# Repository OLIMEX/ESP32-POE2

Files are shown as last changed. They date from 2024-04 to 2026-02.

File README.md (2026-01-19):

# ESP32-POE2
Power Over Ethernet Internet of Things POE IoT board with Espressif ESP32 WiFi, Bluetooth and wired 100Mbit Ethehernet with 25W power delivery

https://www.olimex.com/Products/IoT/ESP32/ESP32-POE2/open-source-hardware

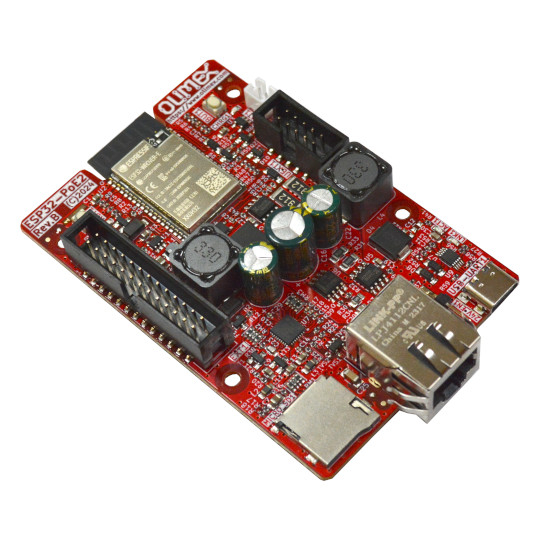
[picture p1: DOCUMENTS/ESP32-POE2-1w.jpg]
ESP32-POE2-1w


## Licensee
* Hardware is released under CERN Open Hardware Licence Version 2 - Strongly Reciprocal
* Box design is released under CC BY 4.0 License
* Software is released under GPL V3 Licensee
* Documentation is released under CC BY-SA 4.0

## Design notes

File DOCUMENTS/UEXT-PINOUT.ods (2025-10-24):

 |  |  |  | UEXT
RESISTOR1 | MUX2 | Signal | Pin# |  | Pin# | Signal | MUX2 | RESISTOR1
- | - | 3.3V OUT | 1 |  | 2 | GND | - | -
NO | NO | GPIO4 | 3 |  | 4 | GPI36 | NO | 10K
2.2K | NO | GPIO333 | 5 |  | 6 | GPIO13 | NO | 10K
10K | SD CMD | GPIO15 | 7 |  | 8 | GPIO2 | SD DATA | 2.2K
NO | SD CLK | GPIO14 | 9 |  | 10 | GPIO5 | NO | 10K
 | 1Some pins have pull-up resistors, that might affect the levels or readings. 2All pins are also routed and available at the EXT1 connector. 3By default ESP32-POE2 is manufactured with ESP32-WROVER module,for ESP32-WROOM module pin #5 would be routed to GPIO16.

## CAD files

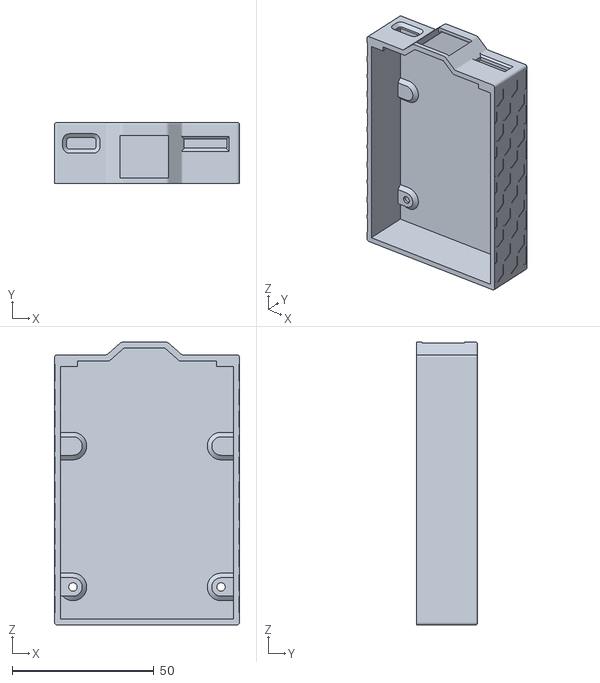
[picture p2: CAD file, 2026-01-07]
HARDWARE/ESP32-PoE2_Rev_B/3D printed case/esp32-poe2 v16_bottom.stl
65.2 x 21.6 x 99.7

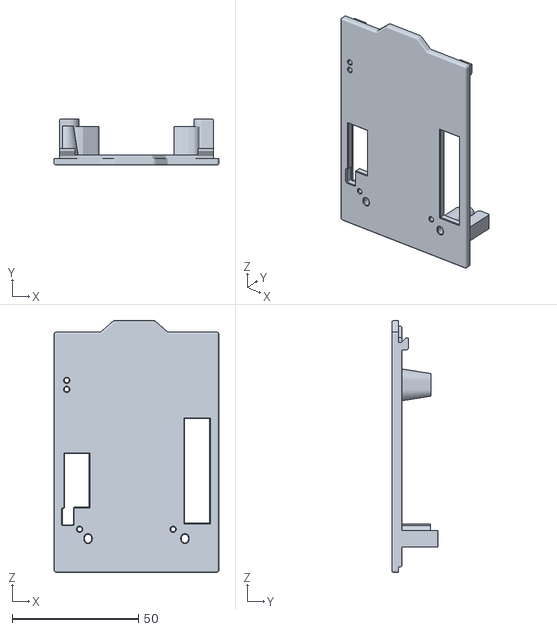
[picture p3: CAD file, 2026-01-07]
HARDWARE/ESP32-PoE2_Rev_B/3D printed case/esp32-poe2 v16_top.stl
65.2 x 18.4 x 99.7

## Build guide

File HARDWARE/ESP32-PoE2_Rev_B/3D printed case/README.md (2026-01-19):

Box can be purchased from here: https://www.olimex.com/Products/IoT/ESP32/BOX-ESP32-POE2/

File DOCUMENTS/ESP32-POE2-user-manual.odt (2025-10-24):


ESP32-POE2

User Manual

Document revision 2.7, October 2025 | www.olimex.com

# 1. Introduction to ESP32-POE2

ESP32-POE2 (https://www.olimex.com/Products/IoT/ESP32/ESP32-POE2/open-source-hardware) is an upgraded version of the popular ESP32-PoE (https://www.olimex.com/Products/IoT/ESP32/ESP32-POE/open-source-hardware) board with more power output capabilities. ESP32-POE2 is an IoT based on ESP32-WROVER-E WIFI/BLE/Ethernet development board with Power-Over-Ethernet feature. The ESP32-POE2 (https://www.olimex.com/Products/IoT/ESP32/ESP32-POE2/open-source-hardware) allows 25W power negotiation and can provide 24V/12V/5V/3.3V to additional equipment connected to it.

The PoE in ESP32-POE2 (https://www.olimex.com/Products/IoT/ESP32/ESP32-POE2/open-source-hardware) is handled by TPS2378 chip that is IEEE 802.3af-compliant, including pre-standard (legacy) PoE support.

The PoE powering requires at least 37V DC to operate successfully. The board can take power from the Ethernet cable and can be expanded with sensors and additional peripherals. Perfect solution for Internet-of-Things projects.

The board is considered Open Source Hardware, design files are released under CERN Open Hardware Licence Version 2 - Strongly Reciprocal. Design files can be found at our GitHub.

Software is released under GPL V3 License and documentation is released under CC BY-SA 4.

+ Important notice: ESP32-POE2 (https://www.olimex.com/Products/IoT/ESP32/ESP32-POE2/open-source-hardware) has no galvanic isolation on Ethernet's power supply, this might be a problem for ground loops. This also means that when you program the board via the micro USB connector the Ethernet cable should be disconnected (if you have power over the Ethernet enabled)! Any board with own external power supply attached to ESP32-POE2 can be dangerous. Consider using Olimex USB-ISO (https://www.olimex.com/Products/USB-Modules/USB-ISO/) to protect your computer and board from accidental short circuit.

## ESP32-POE2 features

- ESP32-WROVER-E-N4R8 – WiFi and bluetooth module with 4MB flash, 8MB PSRAM
- CE-RED and LVD certification
- Original design by OLIMEX Ltd
- Low power design – 200uA consumption in deep sleep
- Ethernet 100Mb interface with IEEE 802.3 PoE support
- USB-C connector for ESP32 programming
- MicroSD card working in 1 bit mode (3 more GPIOs)
- LiPo battery charger with LiPo battery connector
- Battery level monitor pin on ADC
- External power supply detection pin on ADC
- Total output for external circuits – 25W max, max power distributed as follows: - 0.75A at 24V or 1.5A at 12V (selectable by jumper); - 1.5A at 5V; - 1A at 3.3V.
- UEXT (https://www.olimex.com/Products/Modules/) connector
- EXT connector
- User button
- Reset button
- PCB dimensions: (59 x 90)mm ~ (2.32 x 3.54)in

## PoE standard

ESP32-POE2 (https://www.olimex.com/Products/IoT/ESP32/ESP32-POE2/open-source-hardware) follows the original IEEE 802.3af PoE standard and provides up to 25 W of DC power (PoE requires minimum 44 V DC and 350 mA). Only 23 W is assured to be available at the powered device as some power dissipates in the cables.

The board is configured to work in PoE type 2 class 4 mode (PoE+ or IEEE 802.3at) – it draws 12.95 at minimum up to 25.50W maximum. Notice that network equipment usually reserves the maximum wattage for the port, meaning your switch will likely reserve 30W for each ESP32-POE2 connected to it.

The board requires networking equipment that complies with IEEE 802.3at. It is STRONGLY recommended to use isolated PoE equipment.

ESP32-POE2 uses LAN connector that is compatible with both mode A or mode B power delivery method.

## Differences between ESP32-POE2 and ESP32-POE-ISO

ESP32-POE-ISO has limited output voltage range. There are only 5V and 3.3V outputs available, while ESP32-POE2 has also 12V DC or 24V DC.

ESP32-POE2 operates in PoE type 2 class 4 mode (PoE+ or IEEE 802.3at), wherever ESP32-POE-ISO operates in PoE type 1 class 0 mode (PoE or IEEE 802.3af).

ESP32-POE2 (https://www.olimex.com/Products/IoT/ESP32/ESP32-POE2/open-source-hardware) is NOT galvanically isolated which means that it’s not safe to connect it to other devices which use non-isolated power supply. ESP32-POE-ISO is galvanically isolated.

+ YOU SHOULD NOT CONNECT ESP32-POE2 to computer’s USB port while it’s powered by Ethernet POE!!! If you connect USB while ESP32-POE2 is powered by Ethernet you will damage the board or your computer or both. This also voids the warranty!

+ The board is susceptible to grounds loops. Make sure your PoE network equipment is isolated. Measure for voltage difference between different grounds before attaching devices to ESP32-POE2.

+ The most optimal setup for the board is being connected just to the PoE Ethernet cable and all attached peripherals are attached only to ESP32-POE2. No sources of power with different grounds should be attached at the same time. Additional boards that are attached to ESP32-POE2 and are also attached to other sources of power supply (being powered from other sources) can also cause problems!

## Order codes for ESP32-POE2 and accessories

ESP32-POE2 (https://www.olimex.com/Products/IoT/ESP32/ESP32-POE2/open-source-hardware) Commercial temperature grade 0-70C board with internal antenna

USB-CABLE-A-TO-C-1M (https://www.olimex.com/Products/Components/Cables/USB-CABLE-A-TO-C-1M/) 1 meter USB-A to USB-C cable for ESP32-POE2 powering and

programming

Ethernet-CABLE-1M (https://www.olimex.com/Products/Components/Cables/Ethernet-CABLE-1M/) 1 meter Cat 5e Gigabit Ethernet cable with unshielded RJ45 connectors

BOX-ESP32-POE2 (https://www.olimex.com/Products/IoT/ESP32/BOX-ESP32-POE2/) Plastic box for ESP32-POE2

USB-ISO (https://www.olimex.com/Products/USB-Modules/Isolators/USB-ISO/) Galvanic USB isolator to protect your PC from electrical problems with ESP32-POE2

BATTERY-LIPO1400mAh (https://www.olimex.com/Products/Power/Lipo-battery/BATTERY-LIPO1400mAh/) Lipo battery 3.7V 1400mAh – note these batteries can be shipped only by ground so we can deliver only to EU destinations.

UEXT modules (https://www.olimex.com/Products/Modules/) Different sensors, relays, LCDs, RTC, GSM, GPS, accessories which can be connected to UEXT connector

# 2. Hardware

## ESP32-POE2 layout

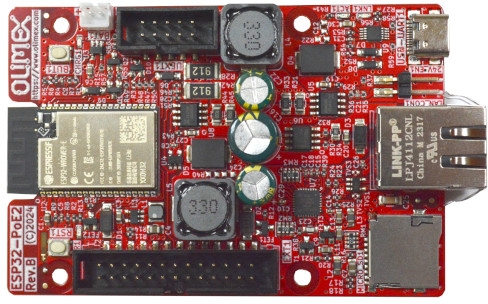
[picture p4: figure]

MicroSD card

(1-bit SD mode)

12V/24V jumper selector

LiPo battery connector

User button BUT1

EXT1 connector

RESET button RST1

Ethernet connector

USB-C for power and programming

UEXT connector

## ESP32-POE2 pins and connectors

+ ESP32 chip and modules have very good pin multiplexing. You can define any free GPIO pin for almost any goal.

+ ESP32-POE2 uses WROVER chip, and it uses GPIO16 and GPIO17 for PSRAM. This is important when you are defining the pins for the Ethernet or using GPIO16 at the UEXT.

ESP32-POE2 with WROVER module remaps GPIO16 to GPIO33 (so, for example, at UEXT pin #5 you have GPIO33 instead of GPIO16) and GPIO17 to GPIO0 (this is the Ethernet clock source).

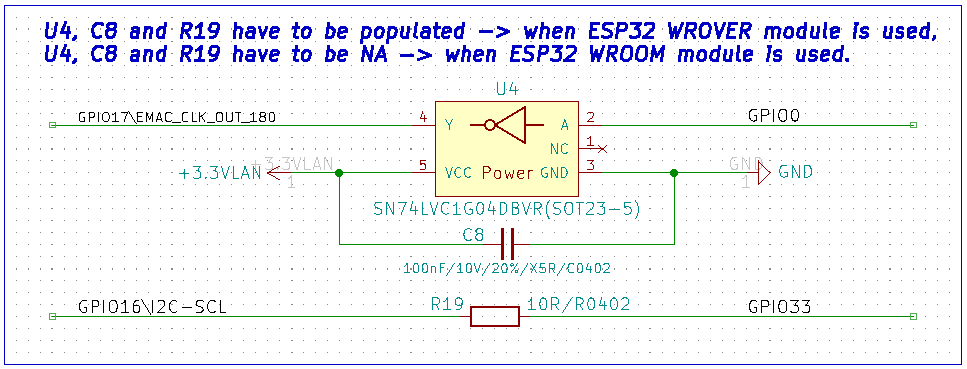
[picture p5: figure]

### Power sense and battery level measurement

- External power sense available on GPI39

- Battery measurement disabled by default (for an additional free GPIO), but can be enabled by SMT jumper change

- Close SMT jumper BAT_SENS_E1 (solder its pads together) to enable battery measurement on GPI35.

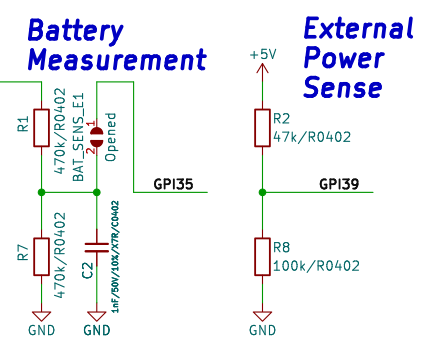
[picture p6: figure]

Notice about the battery measurement resistor divider coefficient is 2 = (R1+R7)/R7 and maximum battery charger voltage is around 4.2V, this leaves ADC values up to 2.1V. This means VREF needs to be set in ADC_ATTEN_DB_11 range (150 mV ~ 3100 mV).

### Buttons

The ESP32-POE2 board has two button. One user button BUT1 and a reset button RST1.

By default button BUT1 is a user button since the board automatically enters bootloader mode. It is connected to GPI34 (GPIO34 can only be input, hence we’ve named it GPI34). Notice that BUT1 can be configured as on-demand BOOT button if you solder R6 pads together (or if you solder 0R resistor in 0402 package on same R6 pads). BOOT button can then be used to manually force boot mode.

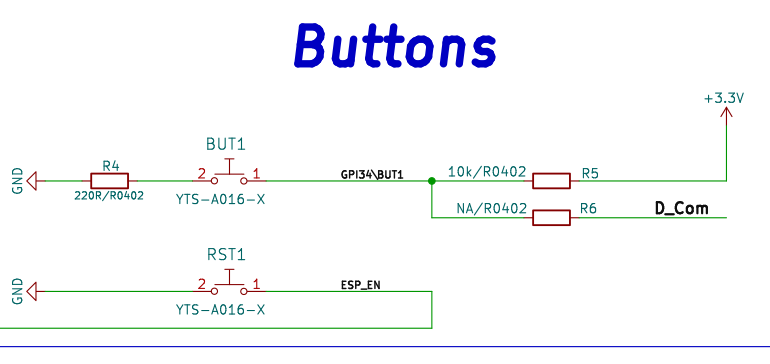
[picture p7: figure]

### SD card connector (1-bit SD interface)

Notice that the SD card pins are multiplexed with pins #7, #8, #9 of the UEXT (typically used for SPI). If you wish to use those pins at the UEXT you’d have to time share with the SD card using the different chip selects. It is important to notice the SD card is configured in 1-bit SD mode when considering the software.

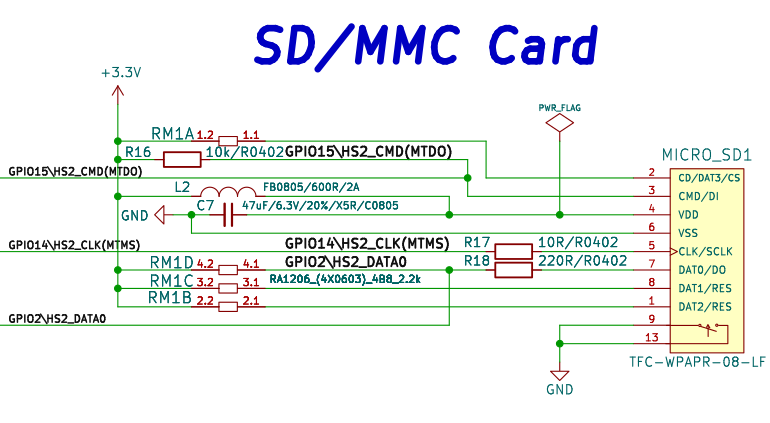
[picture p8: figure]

### UEXT connector

UEXT connector stands for Universal EXTension connector and contain +3.3V, GND, I2C, SPI, UART signals. It is usually used to attach external modules without soldering.

UEXT is 0.1” 2.54mm step boxed plastic connector. All signals are at 3.3V levels. GPIO16 is replaced by GPIO33 in boards with ESP32 WROVER module (all ESP32-POE2 boards use WROVER, so this is always true).

Pins #7, #8, #9 are multiplexed with the SD card, if you don’t have or you don’t need SD card it is fine to use, else you’d need to time-share the functionality between the UEXT and the SD card (using the different chip selects).

These are suggested usage for the pins for compatibility with Olimex-made modules, but since ESP32 chip has good multiplexing they can be defined for other uses. Notice that you need to define the pins in your code (e.g. define them via software means) for the intended usage. For example, if you use GPIO33 for I2C SCL and GPIO13 for I2C SDA you need to define them in your code (in Arduino IDE it is usually done with “Wire.begin (13, 33);”).

Olimex has developed number of MODULES (https://www.olimex.com/Products/Modules/) with this connector. There are temperature, humidity, pressure, magnetic field, light sensors. Modules with LCDs, LED matrix, Relays, Bluetooth, Zigbee, WiFi, GSM, GPS, RFID, RTC, EKG, sensors and etc.

You can find excerpt from the schematic of the UEXT on the next page.

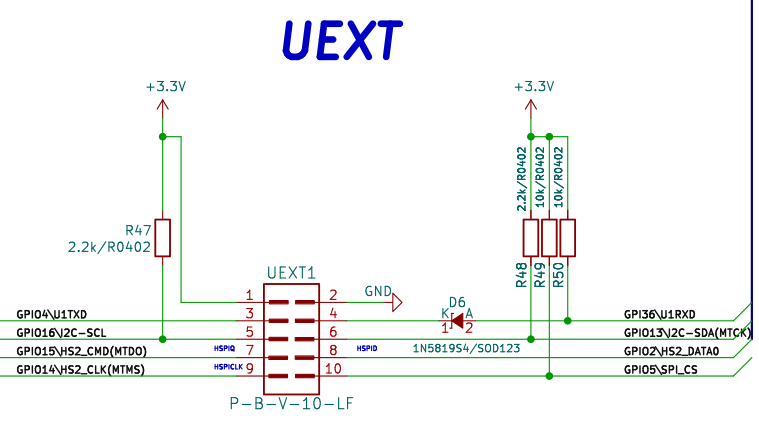
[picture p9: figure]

Important: GPIO16 is replaced by GPIO33 due to the board using WROVER chip (the schematic is made for both variants, but WROVER variant was never manufactured).

### EXT1 connector

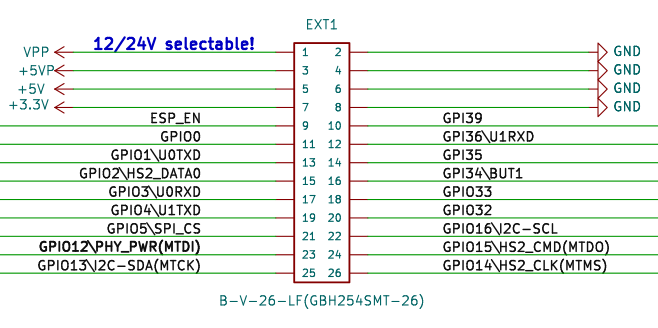
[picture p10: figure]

Again notice about GPIO33 and GPIO16, when the WROVER module is used (by default), there is no GPIO16! And GPIO33 goes to both pin #18 and pin #22!

Same for GPIO0 – it will be used for Ethernet clock, if you decide it for other uses it will affect the Ethernet!

### Power supply

VPP selectable 12V/1.5A or 24V/0.75A output from PoE, depending on 24V_E1 PTH jumper state

+5VP 5V/1.5A output from PoE

+5V 1. can be output or input;

2. when board is connected to USB or to Ethernet PoE this line can be used as output and power other circuits;

3. if you want to use as input i.e. to power the board from external 5V on this pin sure board is not connected to the USB!

+3.3V output which can source up to 0.5A @ 3.3V i.e. (1.65W)

### GPIOs

ESP_EN resets ESP32 module;

GPIO0 is used for Ethernet clock;

GPIO16, GPIO17 are used for the PSRAM;

GPIO1 is used for the serial line and programming;

GPIO2, GPIO14, GPIO15 are used for the SD-card, if no SD card is present these are free to use, else you can time-share using the chip select;

GPIO2, GPIO4, GPIO5, GPIO13, GPIO14, GPIO15, GPIO33, GPIO36 are shared on both UEXT and EXT1,2 headers so if you use them at one connector do not use at the other;

GPIO33 is routed in place of GPIO16 at the header and the UEXT (since the board uses WROVER chip);

GPI39 is used to measure external power supply voltage;

GPI34 is connected to used button and have 10K pullup;

GPI35 is free to use but can be connected to measure the LiPo battery voltage if SENS_BAT_E1 solder jumper.

Notice that pins named GPI* can only be inputs (unlike GPIO*). This is limitation from the ESP32 chip itself.

## ESP32-POE2 schematics

ESP32-POE2 (https://www.olimex.com/Products/IoT/ESP32/ESP32-POE2/open-source-hardware) latest schematic is on GitHub (https://github.com/OLIMEX/ESP32-POE2)

## ESP32-POE2 powering details

(https://www.olimex.com/Products/Retro-Computers/AgonLight2/open-source-hardware)

ESP32-POE2 (https://www.olimex.com/Products/IoT/ESP32/ESP32-POE2/open-source-hardware) can be powered by 4 sources:

- Ethernet PoE, notice this is class 4 PoE device requires at least 12.95W and can go up to 25.5W. Notice that your network equipment will allocate the maximum wattage for the port, usually around 30W per device; this is important if you connect multiple ESP32-POE2 boards to the same piece of PSE (Power Sourcing Equipment)!
- USB-C connector
- LiPo battery
- EXT1 pin 5 (+5V) note that this signal is connected to USB 5V signal so when you power with this pin you should not connect the board to the USB! If possible avoid powering from EXT1 to avoid accidental short-circuit!

Power consumption of ESP32-POE2 (https://www.olimex.com/Products/IoT/ESP32/ESP32-POE2/open-source-hardware) is between 50mA and 200mA depending on the operation mode.

A LiPo battery gets charged automatically from other sources of power with about 100mA.

When the LiPo battery is attached and external power supply is missing internal DCDC step-up converter and switching circuit automatically powers ESP32-POE2 from the battery. 1400mAh battery will provide about 8 hours of stand alone operation.

+The LiPo battery connector is JST 2.0 mm connector and with Olimex’s battery polarity. If you use batteries from other manufacturers please make PLUS and MINUS are connected properly else you will damage the board!!!

# 3. Dimensions

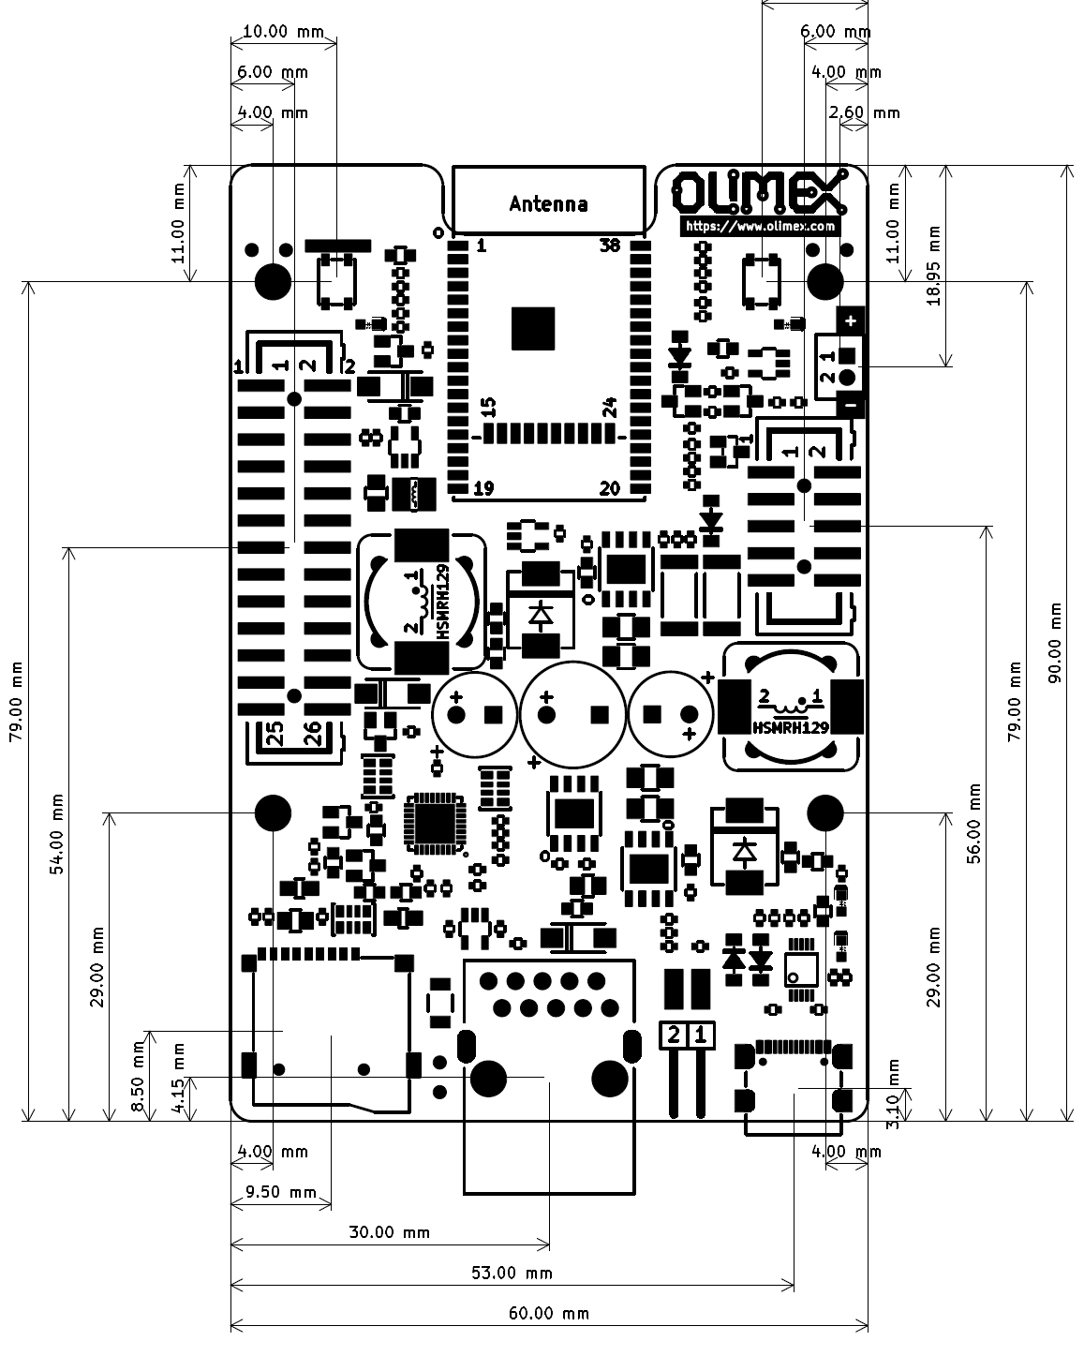
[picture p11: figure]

# 4. Software

(https://www.olimex.com/Products/IoT/ESP32/ESP32-POE2/open-source-hardware)

ESP32-POE2 (https://www.olimex.com/Products/IoT/ESP32/ESP32-POE2/open-source-hardware) uses same software as ESP32-POE which is very popular board and supported by

- Espressif ESP-IDF (https://docs.espressif.com/projects/esp-idf/en/latest/esp32/get-started/)
- MicroPython (https://micropython.org/download/OLIMEX_ESP32_POE/)
- Arduino IDE (https://github.com/OLIMEX/ESP32-POE/tree/master/SOFTWARE/ARDUINO)
- Esphome (https://github.com/esphome/bluetooth-proxies/blob/main/olimex-esp32-poe-iso.yaml)
- PlatformIO (https://docs.platformio.org/en/latest/boards/espressif32/esp32-poe.html)

In your software (for example, Arduino IDE) make sure to enable the PSRAM in the board selector (when board is with ESP32-WROVER-E)!

Software notices:

- Ethernet notice – For the Ethernet operation make sure to properly set the GPIO for the Ethernet clock and the pin for the power enable pin! GPIO12 is used as PHY power pin and GPIO0 is used as clock output pin (when board uses ESP32-WROVER-E module). Under Arduino defines should be like (must be defined before ETH.h):

#ifndef ETH_PHY_TYPE

#define ETH_PHY_TYPE ETH_PHY_LAN8720

#define ETH_PHY_ADDR 0

#define ETH_PHY_MDC 23

#define ETH_PHY_MDIO 18

#define ETH_PHY_POWER 12

#define ETH_CLK_MODE ETH_CLOCK_GPIO0_OUT

#endif

#include <ETH.h>

- I2C (TWI) notice – since the board uses WROVER chip to define the I2C pins at the UEXT connector use GPIO13 for SDA and GPIO33 for SCL. For example, to define in Arduino IDE use:

Wire.begin(13, 33);

Remember to include <Wire.h> at the beginning:

#include <Wire.h>

# 5. FAQ (Frequently Asked Questions)

- Help! Ethernet is not working always upon power-up. If I press the reset or power cycle the board a few times sometimes it starts working. Is my device faulty?
  It is probably because your software didn’t utilize the PHY_PWR pin (GPIO12) properly. This behavior happens when the PHY controller (LAN8720) gets powered before the ESP32 module can generate the PHY clock. What your software should do is hold the LAN8720 in reset for few milliseconds via the PHY_PWR pin and release it from reset only after PHY clock is already generated by the ESP32 module. Simple software workarounds that can be tested are adding delay before Ethernet initialization or toggling GPIO12 to reset only the Ethernet chip until connection is restored.
- Ethernet doesn't work. Is my board defective?
  Make sure you've selected board variant with PSRAM enabled (this board has WROVER module, not WROOM). Make sure your code defines GPIO0 as Ethernet clock source pin.
- Where are the I2C, UART, SPI pins exposed?
  The ESP32 chip has very advanced multiplexing and you can define any free GPIO pin for I2C, UART, SPI operation as long as you are within the maximum supported (some penalties to SPI's maximum frequency apply, when not using the dedicated pins). Notice that some ESP32 pins can only be inputs. Double check if the pins you want to use are free. Defining pins for another function is a purely software effort.
- I want to use the I2C pins at the UEXT but I have problems. I have defined pins 13 and 16 for the I2C. What is the problem?
  The I2C pins at the UEXT are 13 and 33. Pin 16 gets replaced by pin 33 due to the board using WROVER chip (instead of WROOM). Refer to page 9.
- I provide 24V to the Ethernet of ESP32-POE2's but it doesn't seem powered. What is the problem?
  TPS2375PW (Si3402) would NOT work with 24V DC. The recommended voltage is 48V DC and the minimum is around 37V DC. For more info refer to TPS2375PW's (Si3402-B's) datasheet.
- I power the board from the battery connector. The LEDs remain off. Is it broken?
  Probably not. This is a low-power design. The LEDs would not turn on when operating on battery to save power. You need other ways to determine if it works or not. For example, something over the serial lines or over the Ethernet (with no PoE enabled else it would get powered from there).
- What is the power delivery mode of these boards? Is it mode A or mode B?
  ESP32-POE2 uses LAN connector that is compatible with both mode A or mode B. Either one is fine.
- What is the PoE class of ESP32-POE2?
  ESP32-POE2 is set for type 2 class class 4 PoE operation (12.95W-25.5W). Class 4 operation might require more current since it requires at least 12.95W up to 25.5W. Notice that your network equipment will allocate the maximum wattage for the port, usually around 30W per device; this is important if you connect multiple ESP32-POE2 boards to the same piece of PSE (Power Sourcing Equipment)! If you have trouble with powering multiple devices from the same switch then refer to the schematic and unsolder the resistor R34 to switch back to class 0 operation. (0.44W to 12.95W), but this will reduce the wattage available from the board, roughly half of the wattage only will be available.
- R28 and R42 get very hot! What are these components? Are they safe? Can I remove them?
  These resistors are required by the IEEE standards. They are used to maintain power signature (MPS). Search online "maintain power signature poe" to get the general idea.
  Lack of load causes availability problems when using ESP32 power saving modes – the board would consume less wattage than PoE equipment can detect, which leads to PoE equipment shutting the ESP32 board off.
  If you are not using the low power modes of the ESP32 board and the heat from the resistor bothers you, you might try desoldering R28 and R42 and see if that effects your setup negatively. If the board gets shut down, solder them back. Notice that we don't recommend doing so.

# 6. Document revision history

Revision 2.7 October 2025

-Expanded FAQ section;

-Reworked UEXT connector table;

-Expanded I2C clarifications (GPIO16→GPIO33 due to WROVER chip);

-General minor improvements.

Revision 2.6 September 2025

-Clarified multiplexing and cleared UEXT section

Revision 2.5 September 2025

-Added FAQ section

Revision 2.4 March 2025

-Minor improvements and fixes

Revision 2.3 August 2024

-Additional notes about software setup for Ethernet and board selection

Revision 2.2 May 2024

-Fixed mistakes in GPIO descriptions

Revision 2.2 May 2024

-Fixed mistakes in GPIO descriptions

Revision 2.1 May 2024

- Added dimensions;

- Spelling improvements.

Revision 2.0 May 2024

- Fixed wrong info about ESP32 module – the board is manufactured with WROVER module, not WROOM;

- Clarified warnings about isolation;

- Added some extra info about different GPIOs;

- Spelling improvements.

Revision 1.0 April 2024

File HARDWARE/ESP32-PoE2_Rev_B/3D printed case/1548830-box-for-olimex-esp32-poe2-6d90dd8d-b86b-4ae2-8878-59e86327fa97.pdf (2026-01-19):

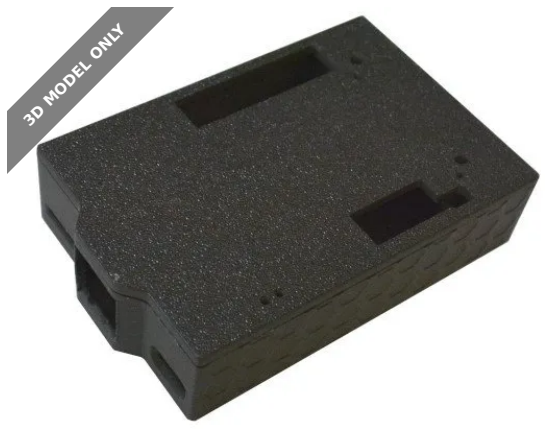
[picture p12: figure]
3D MODEL ONLY

## Summary

ESP32-PoE2 is an Open Source Hardware ESP32-powered WIFI/BLE/ Ethernet development board with Power-Over-Ethernet feature

Gadgets (https://printables.com/model?categoryId=21) > Computers (https://printables.com/model?categoryId=27)

Tags: | esp32 | olimex | esp32poe2

Github project page: OLIMEX/ESP32-POE2: Power Over Ethernet Internet of Things POE IoT board with Espressif ESP32 WiFi, Bluetooth and wired 100Mbit Ethehernet with 25W power delivery (https://github.com/OLIMEX/ESP32-POE2)

Product page: ESP32-POE2 - Open Source Hardware Board (https://www.olimex.com/Products/IoT/ESP32/ESP32-POE2/open-source-hardware)

ESP32-PoE2 is an Open Source Hardware ESP32-powered WIFI/BLE/ Ethernet development board with Power-Over-Ethernet feature.
The PoE is handled by TPS2378PW chip that is IEEE 802.3-compliant, including pre-standard (legacy) PoE support. The PoE powering requires at least 37V DC to operate successfully. The board takes power from the Ethernet cable and can be expanded with sensors and more. Perfect solution for Internet-of-Things projects.
ESP32-POE2 operates in the commercial temperature range (0-70) degrees C.
ESP32-POE2 can power external circuits with 24V/0.75A or 12V/1.5A plus experify3d (https://printables.com/@experify3d_271079)

## Box for Olimex ESP32-POE2

VIEW IN BROWSER (https://printables.com/model/1548830-box-for-olimex-esp32-poe2)

updated 9. 1. 2026 | published 9. 1. 2026

## Model files

5V/1.5A plus 3.3V/1A up to total of 25W of power output. This is when the board is powered from the Power-Over-Ethernet connector.

## License

This work is licensed under a GNU

General Public License v3.0 (https://www.gnu.org/licenses/gpl-3.0.html)

✖ | Sharing without ATTRIBUTION
✔ | Remix Culture allowed
✔ | Commercial Use
✔ | Meets Open Definition
ℹ | Share under the same license

esp32-poe2-v16_top.stl

esp32-poe2-v16_bottom.stl

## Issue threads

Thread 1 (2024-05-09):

Ethernet SD card demo  - esp_eth_driver_install_failed (PlatformIO)

DO7LZ, 2024-05-09:
Hi,

I tried to get the [Simple Ethernet and SD card demo for Arduino](https://raw.githubusercontent.com/OLIMEX/ESP32-POE/master/SOFTWARE/ARDUINO/ESP32_PoE_Ethernet_SD_Card_Arduino/ESP32_PoE_Ethernet_SD_Card_Arduino.ino) example working with PlatformIO. But there seems to be an error with the Ethernet libary.

```
rst:0x1 (POWERON_RESET),boot:0x1b (SPI_FAST_FLASH_BOOT)
configsip: 0, SPIWP:0xee
clk_drv:0x00,q_drv:0x00,d_drv:0x00,cs0_drv:0x00,hd_drv:0x00,wp_drv:0x00
mode:DIO, clock div:2
load:0x3fff0030,len:1184
load:0x40078000,len:13232
load:0x40080400,len:3028
entry 0x400805e4
Card Mounted
E (664) lan87xx: lan87xx_pwrctl(409): power up timeout
E (665) lan87xx: lan87xx_init(491): power control failed
E (665) esp_eth: esp_eth_driver_install(215): init phy failed
[   674][E][ETH.cpp:324] begin(): esp_eth_driver_install failed
```

What I did:

1. Create a new PlatformIO project with board **OLIMEX ESP32-PoE** and Framework Arduino. (platformio/espressif32 v6.6.0)
2. Pasted in the above mentioned example into `main.cpp` and added `monitor_speed = 115200` to `platformio.ini`
3. Inserted SD card and plugged in network and USB to board.
4. Build and upload. Followed by the console output above.

Can anyone give me a little push?

JulesThuillier, 2024-05-16:
Hi !

Same issue here.
Also I cannot get I2C device to work using your basic sample (https://github.com/OLIMEX/ESP32-POE/blob/master/SOFTWARE/ARDUINO/ESP32_PoE_MOD_BME280/ESP32_PoE_MOD_BME280.ino)
Please adivse.

JulesThuillier, 2024-06-06:
@DO7LZ have you found a solution ?

DanKoloff, 2024-06-07:
Regular ESP32-POE config is not suitable for ESP32-POE2. If there is ESP32-POE-WROVER or ESP32-POE-ISO-WROVER config it would be suitable.

ESP32-POE2 uses ESP32-WROVER module that uses GPIO16 and GPIO17 for the internal PSRAM, so you need to define GPIO0 for the Ethernet clock (instead of GPIO17). Else the Ethernet won't work.

And if you need to use GPIO16 (usually used for I2C) change it with GPIO33.

jonathanelmgren, 2024-06-24:
In the latest firmwares of Micropython you should use `ref_clk` and `ref_clk_mode` to set the clock mode for `network.LAN`.

I got it working with this code:

```
import network
import machine
import time

def initialize_ethernet():
    # Configure the PHY power pin as a machine.Pin object
    phy_power = machine.Pin(12, machine.Pin.OUT)
    phy_power.value(0)  # Start with PHY power off
    time.sleep(1)
    phy_power.value(1)  # Power up the PHY
    time.sleep(1)  # Wait for the PHY to power up

    # Define the MDC and MDIO pins as machine.Pin objects
    mdc_pin = machine.Pin(23)
    mdio_pin = machine.Pin(18)
    ref_clk_pin = machine.Pin(0)

    try:
        # Initialize the LAN interface with the correct PHY type and parameters
        lan = network.LAN(
            mdc=mdc_pin,  # MDC pin as machine.Pin
            mdio=mdio_pin,  # MDIO pin as machine.Pin
            power=phy_power,  # PHY power pin as machine.Pin
            phy_type=network.PHY_LAN8710,  # PHY type
            phy_addr=0,  # PHY address
            ref_clk=ref_clk_pin,  # Reference clock pin as machine.Pin
            ref_clk_mode=machine.Pin.OUT,  # Reference clock mode as output
        )
        lan.config(hostname="esp32-ethernet-client")
        lan.active(True)
        time.sleep(2)  # Allow the interface to stabilize

        while True:
            if lan.isconnected():
                print("Ethernet is supported and connected.")
                print("Network config:", lan.ifconfig())
            else:
                print(
                    "Ethernet is supported but not connected. Please connect an Ethernet cable."
                )
            time.sleep(5)
    except Exception as e:
        print("Error initializing Ethernet:", e)

# Run the initialization function
initialize_ethernet()
```

Working both with PoE and USB with regular Ethernet. Firmware used was https://micropython.org/download/ESP32_GENERIC/ and latest release from `Firmware (Support for SPIRAM / WROVER)` section

DO7LZ, 2024-10-11:
My solution for the problem:

Create a new PlatformIO project with board Espressif **ESP-WROVER-KIT** instead of OLIMEX ESP32-PoE and Framework Arduino.

Paste the example in `main.cpp` and add the following directly before `#include <ETH.h>`:

```
#ifndef ETH_PHY_TYPE
#define ETH_PHY_TYPE ETH_PHY_LAN8720
#define ETH_PHY_ADDR 0
#define ETH_PHY_MDC 23
#define ETH_PHY_MDIO 18
#define ETH_PHY_POWER 12
#define ETH_CLK_MODE ETH_CLOCK_GPIO0_OUT
#endif
```

This is also mentioned in the actual user manual.
With this the example seems to work. It's getting an IP address via DHCP and is able to send a GET request to google.com and prints out the response. On push of BUT1 the files are properly written to SD card. I don't have tested any other things yet.

Closed 2024-10-11.

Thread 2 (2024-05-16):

I2C does not does work on pins 13 - 16. Why is GPIO16 connected to GPIO33 through a 10ohm resistor

JulesThuillier, 2024-05-16:
Using the ESP-POE2 board and Olimex BME280 board I tried the simple example provided by Olimex (https://github.com/OLIMEX/ESP32-POE/blob/master/SOFTWARE/ARDUINO/ESP32_PoE_MOD_BME280/ESP32_PoE_MOD_BME280.ino), the I2C communication with BME280 does not work. Using a protocol analyser I see data on SDA (GPIO13) but SCL (GPIO16) is always HIGH.

Moving forward with my investigation, I look at ESP-POE2 schematic and see the following connection :
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
Can somebody explain why is this here ?

So I tried to replace SCL pin with GPIO5, and tada ! It works.
It is not really a solution in itself because your UEXT connectors uses GPIO16 for SCL.

Last test was to remove R19, and still did not work. I finally stumbled on this piece of information :
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

And that seems to be the answer. It's a bit confusing that this exact pin was chosen for UEXT SCL pin...
Any plan to fix this ?

DanKoloff, 2024-06-07:
This is not an issue to fix. Just we designed the board to be suitable for two types of ESP32 modules - with or without PSRAM (our ESP32-POE and ESP32-POE-ISO modules are designed the same modules).

The ESP32 module without PSRAM is ESP32-WROOM and the ESP32 module with PSRAM is called ESP32-WROVER.

By default in ESP32-POE2 we place the ESP32-WROVER module with PSRAM.

The difference between ESP2-WROOM and ESP32-WROVER is that the ESP32-WROVER uses two of the GPIOs for the PSRAM (GPIO16 and GPIO17). So in boards with ESP32-WROVER module (like ESP32-POE2) - Ethernet clock is GPIO0 instead of GPIO17 and GPIO33 is routed to the UEXT (instead of GPIO16).

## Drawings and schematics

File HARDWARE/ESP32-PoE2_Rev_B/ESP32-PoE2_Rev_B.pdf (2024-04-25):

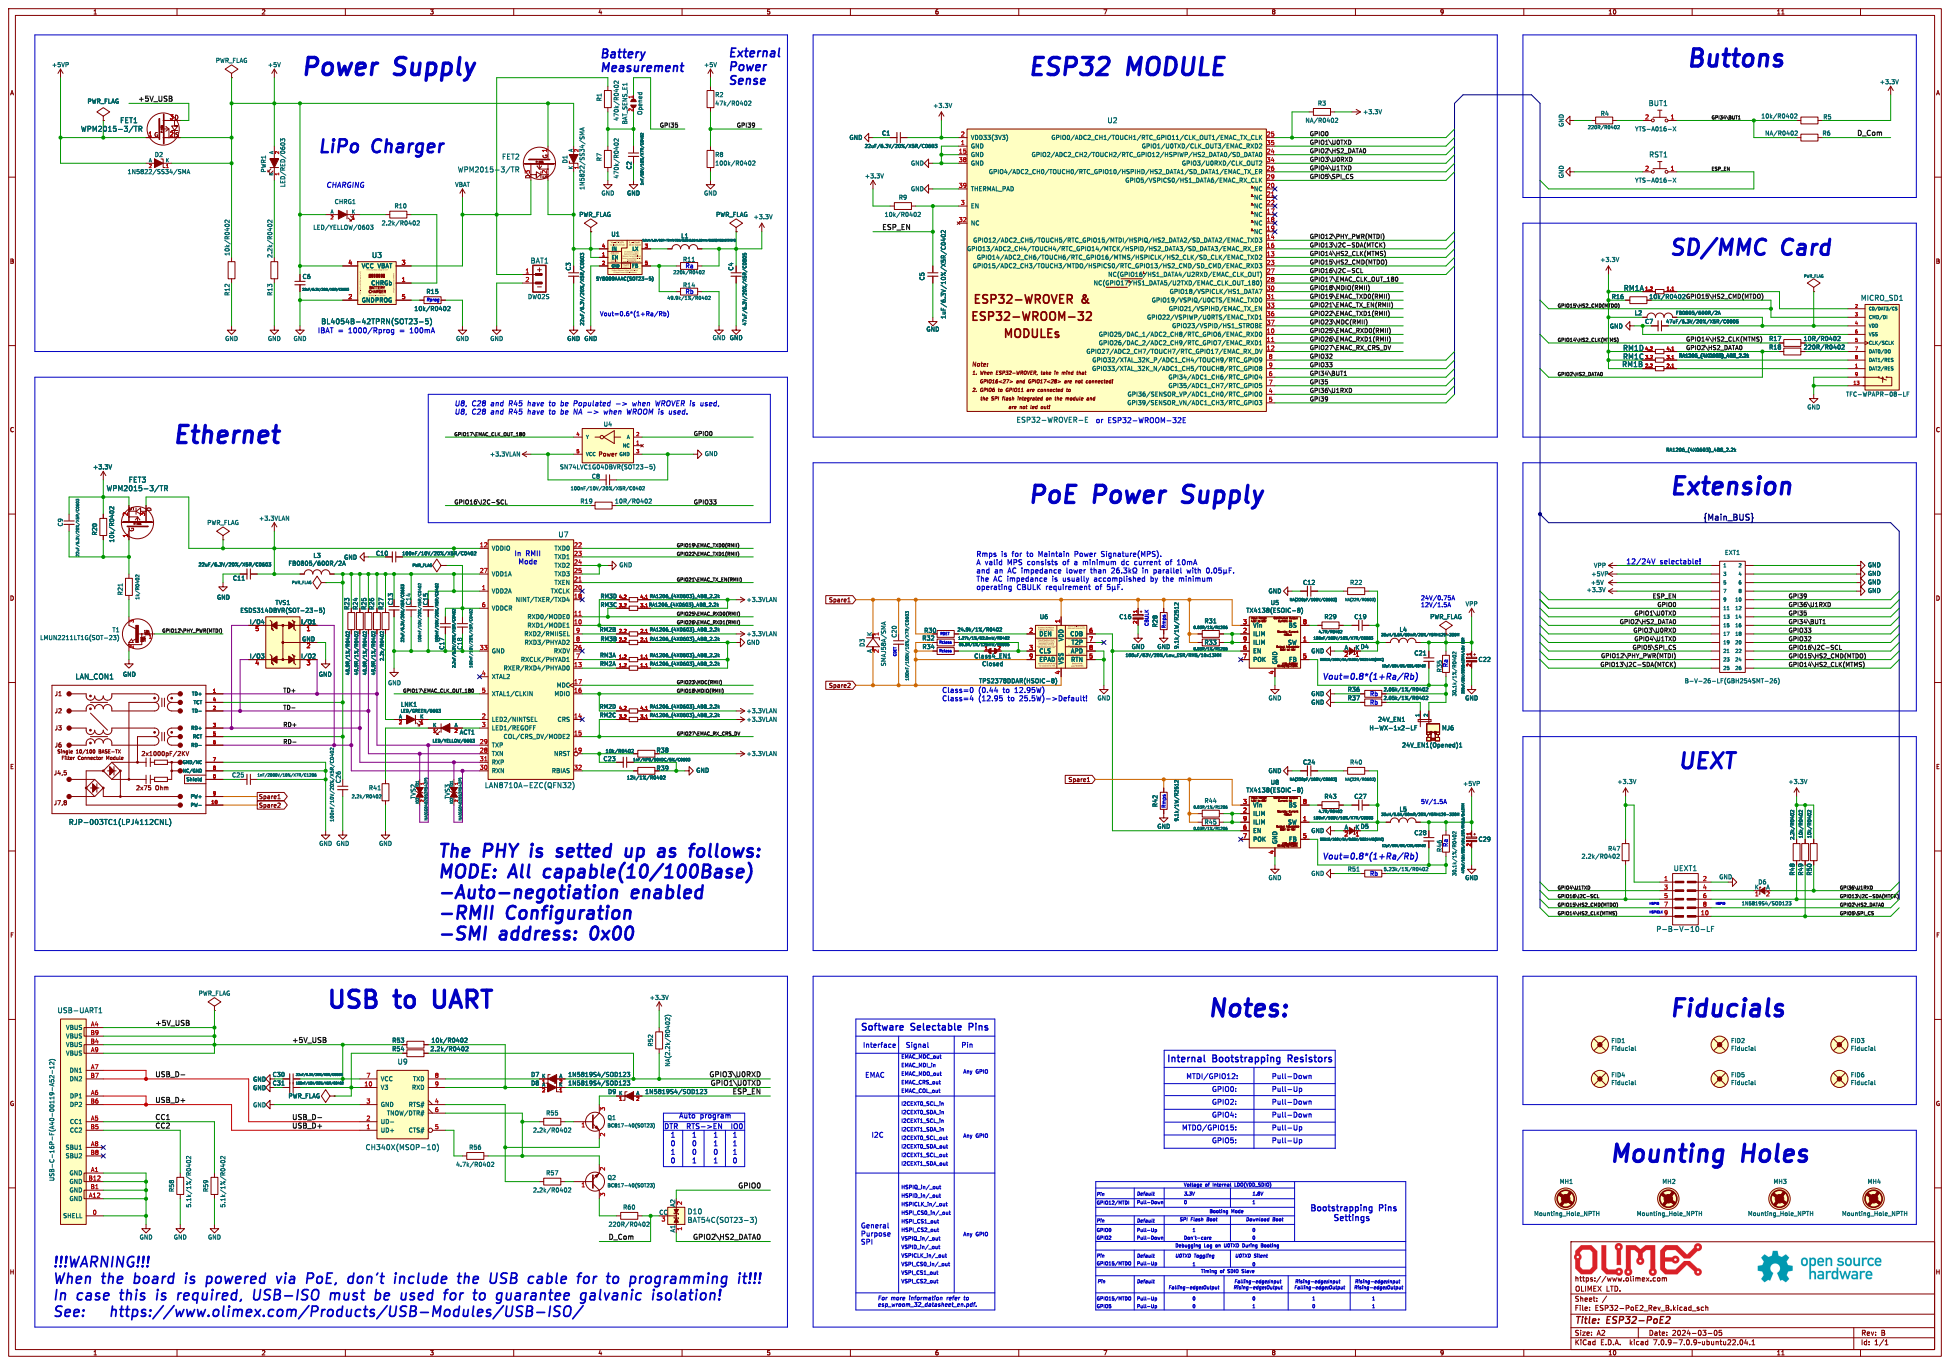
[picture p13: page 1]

2. 2. 2. 2. 2. 2. 2. GPIO6 to GPIO11 are connected to
22 GPIO15/ADC2_CH3/TOUCH3/MTDO/HSPICS0/RTC_GPIO13/HS2_CMD/SD_CMD/EMAC_RXD3

Donotfloat. Enablecontrol. FB Input Current,I(FB)=50nA(max) FeedbackReferenceVoltage,V(REF)=0.6V

are not led out! ESP32-WROOM-32

4 RTN 5 CDB 6 T2P 7 APD 8 EPAD 9 U6 TPS2378DDAR(HSOIC-8) 1 2 Class4_EN1 Closed GND RM1A 1.2 1.1 RA1206_(4X0603)_4B8_2.2k R22

GND GND GND GND RM1A

TFC-WPAPR-08-LF GND

Rmps is for to Maintain Power Signature(MPS). A valid MPS consists of a minimum dc current of 10mA

GPIO25\EMAC_RXD0(RMII)
1 Vout=0.8*(1+Ra/Rb) Rmps

2 D3 SMAJ58A/SMA AuxiliaryPowerDetect Activelowindicatestype2 Activelow,open-drainconverterdisable output,referencedtoRTN. Connect24.9þÿk©toVDD for detection. ConnectresistorfromCLS toVSStoprogram classificationcurrent.

4 RTN 5 CDB 6 T2P 7 APD 8 EPAD 9 R32 1.27k/1%/62.5mW/R0402 R34 66.5R/1%/125mW/R0805 R30 24.9k/1%/R0402

If notused,connectAPD toRTN. PSEconnectedor APD active. ThePowerPadTMmustbe connectedtoVSS.VDD

The controllerplacesa voltageof approximately 2.5Vacrosstheexternal resistorwheneverthevoltage differentialbetweenVDD andVSS liesfromabout10.9Vto22V. Drain ofPoEpass MOSFET.

100nF/100V/10%/X7R/C0603 GND GND GND GND

Rb Vout=0.8*(1+Ra/Rb) Rb

The PHY is setted up as follows:
MODE: All capable(10/100Base)
-RMII Configuration
-SMI address: 0x00

1 Falling-edge:Input Timing of SDIO Slave GPIO0: Booting Mode

Pull-Up Any GPIO

Rising-edge:Input U0TXD Silent Debugging Log on U0TXD During Booting

Falling-edge:Output 0 U0TXD Toggling

!!!WARNING!!!
When the board is powered via PoE, don't include the USB cable for to programming it!!!
In case this is required, USB-ISO must be used for to guarantee galvanic isolation!

1 Rising-edge:Output 0 Pin GPIO15/MTDO

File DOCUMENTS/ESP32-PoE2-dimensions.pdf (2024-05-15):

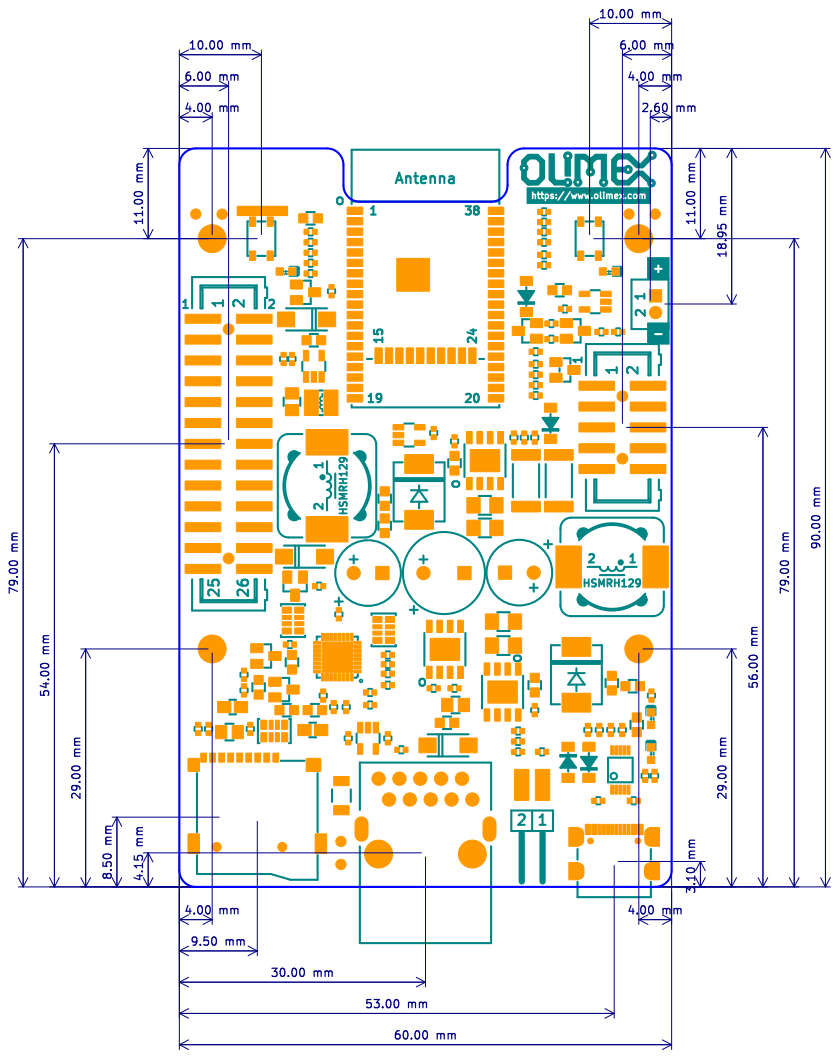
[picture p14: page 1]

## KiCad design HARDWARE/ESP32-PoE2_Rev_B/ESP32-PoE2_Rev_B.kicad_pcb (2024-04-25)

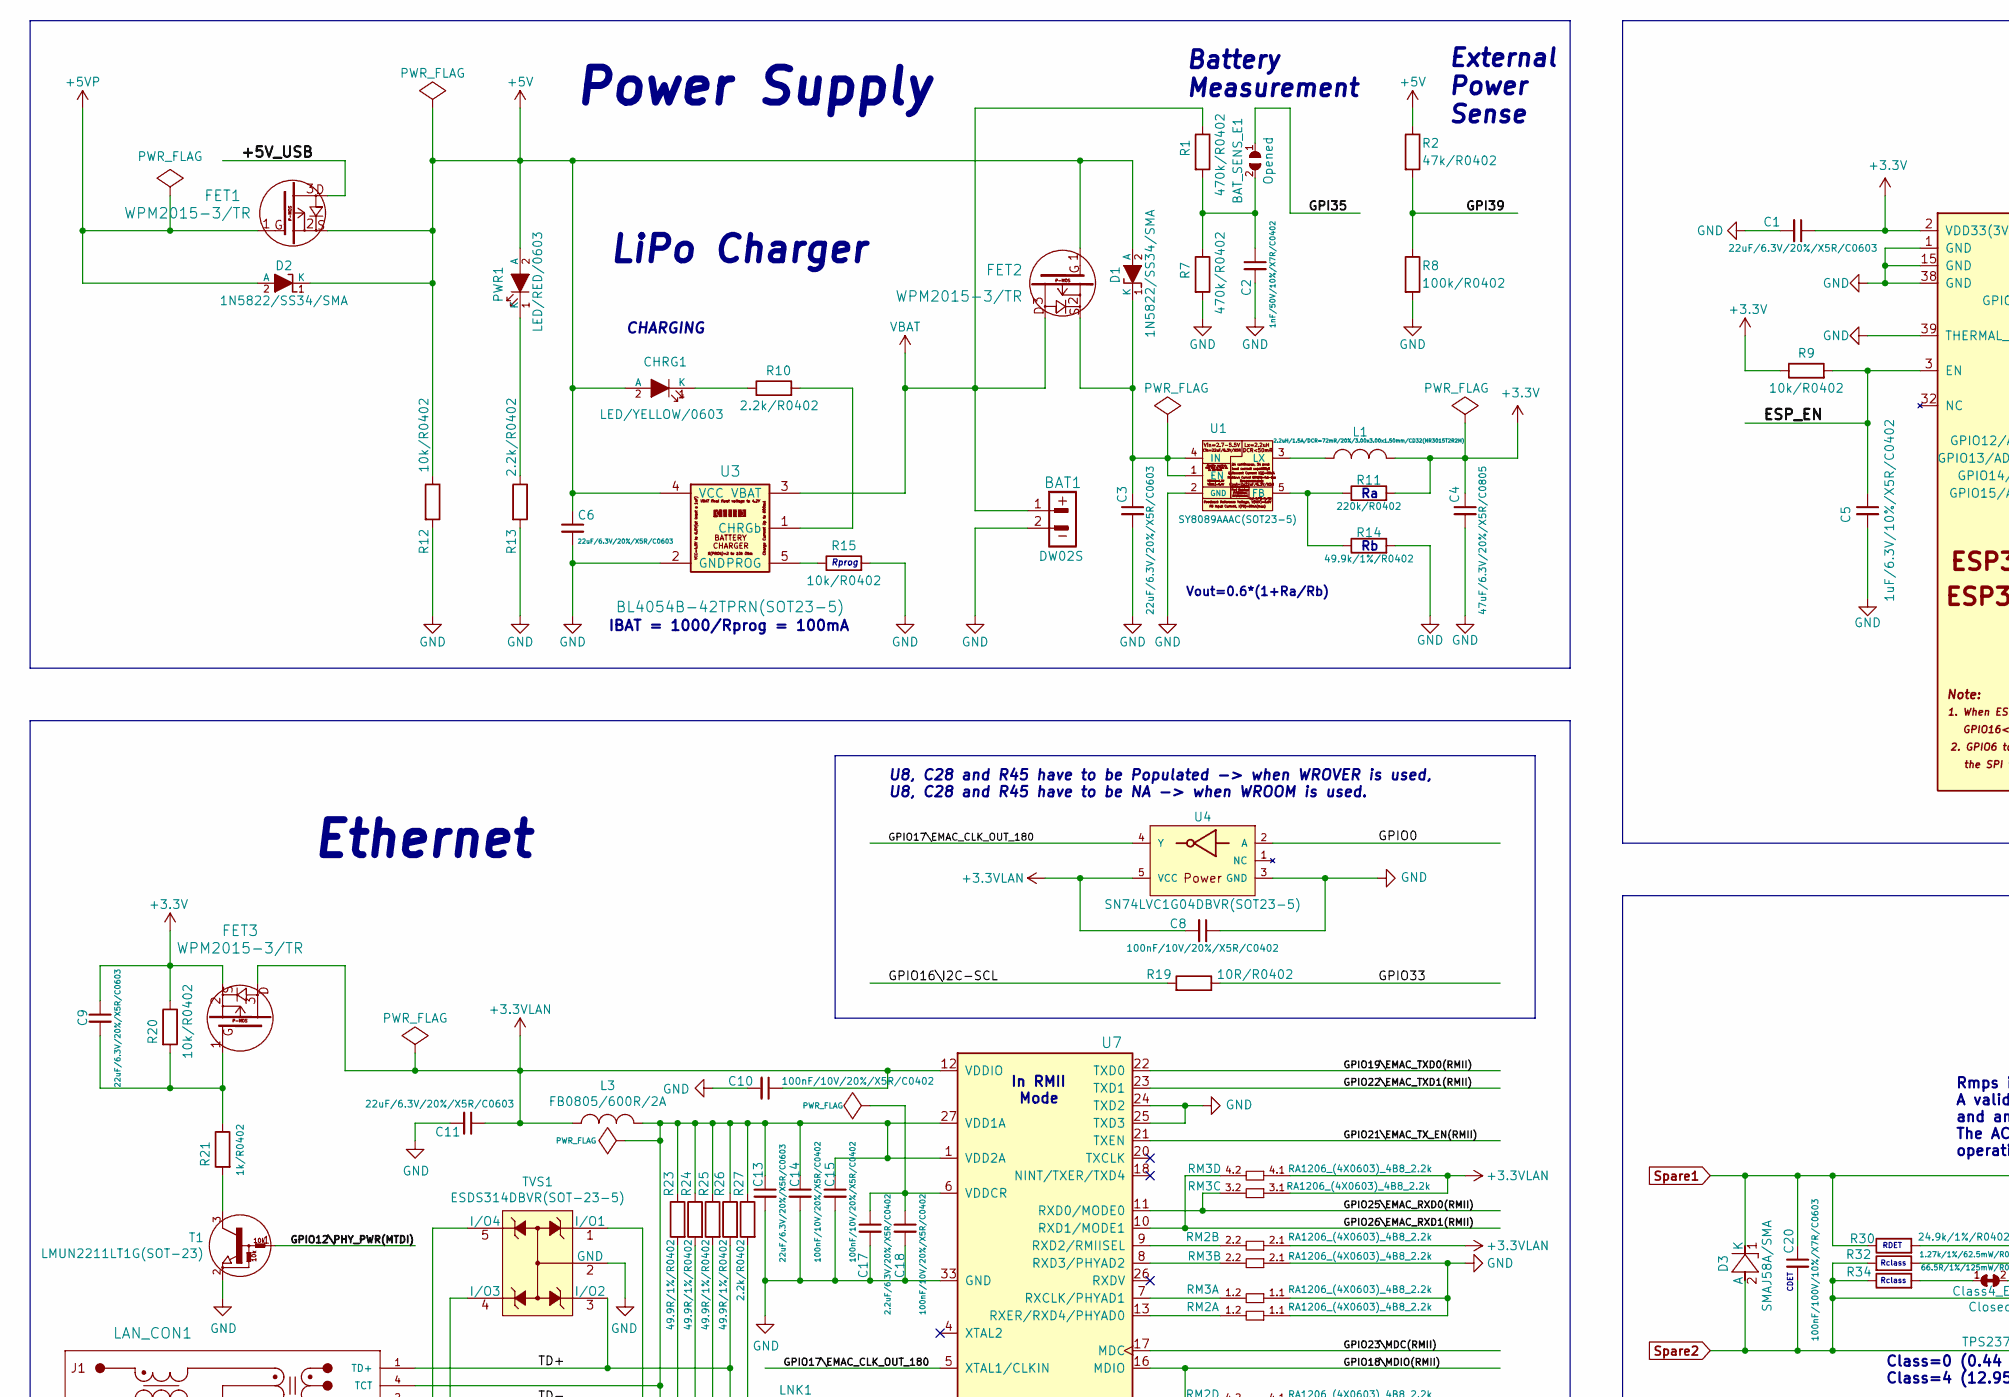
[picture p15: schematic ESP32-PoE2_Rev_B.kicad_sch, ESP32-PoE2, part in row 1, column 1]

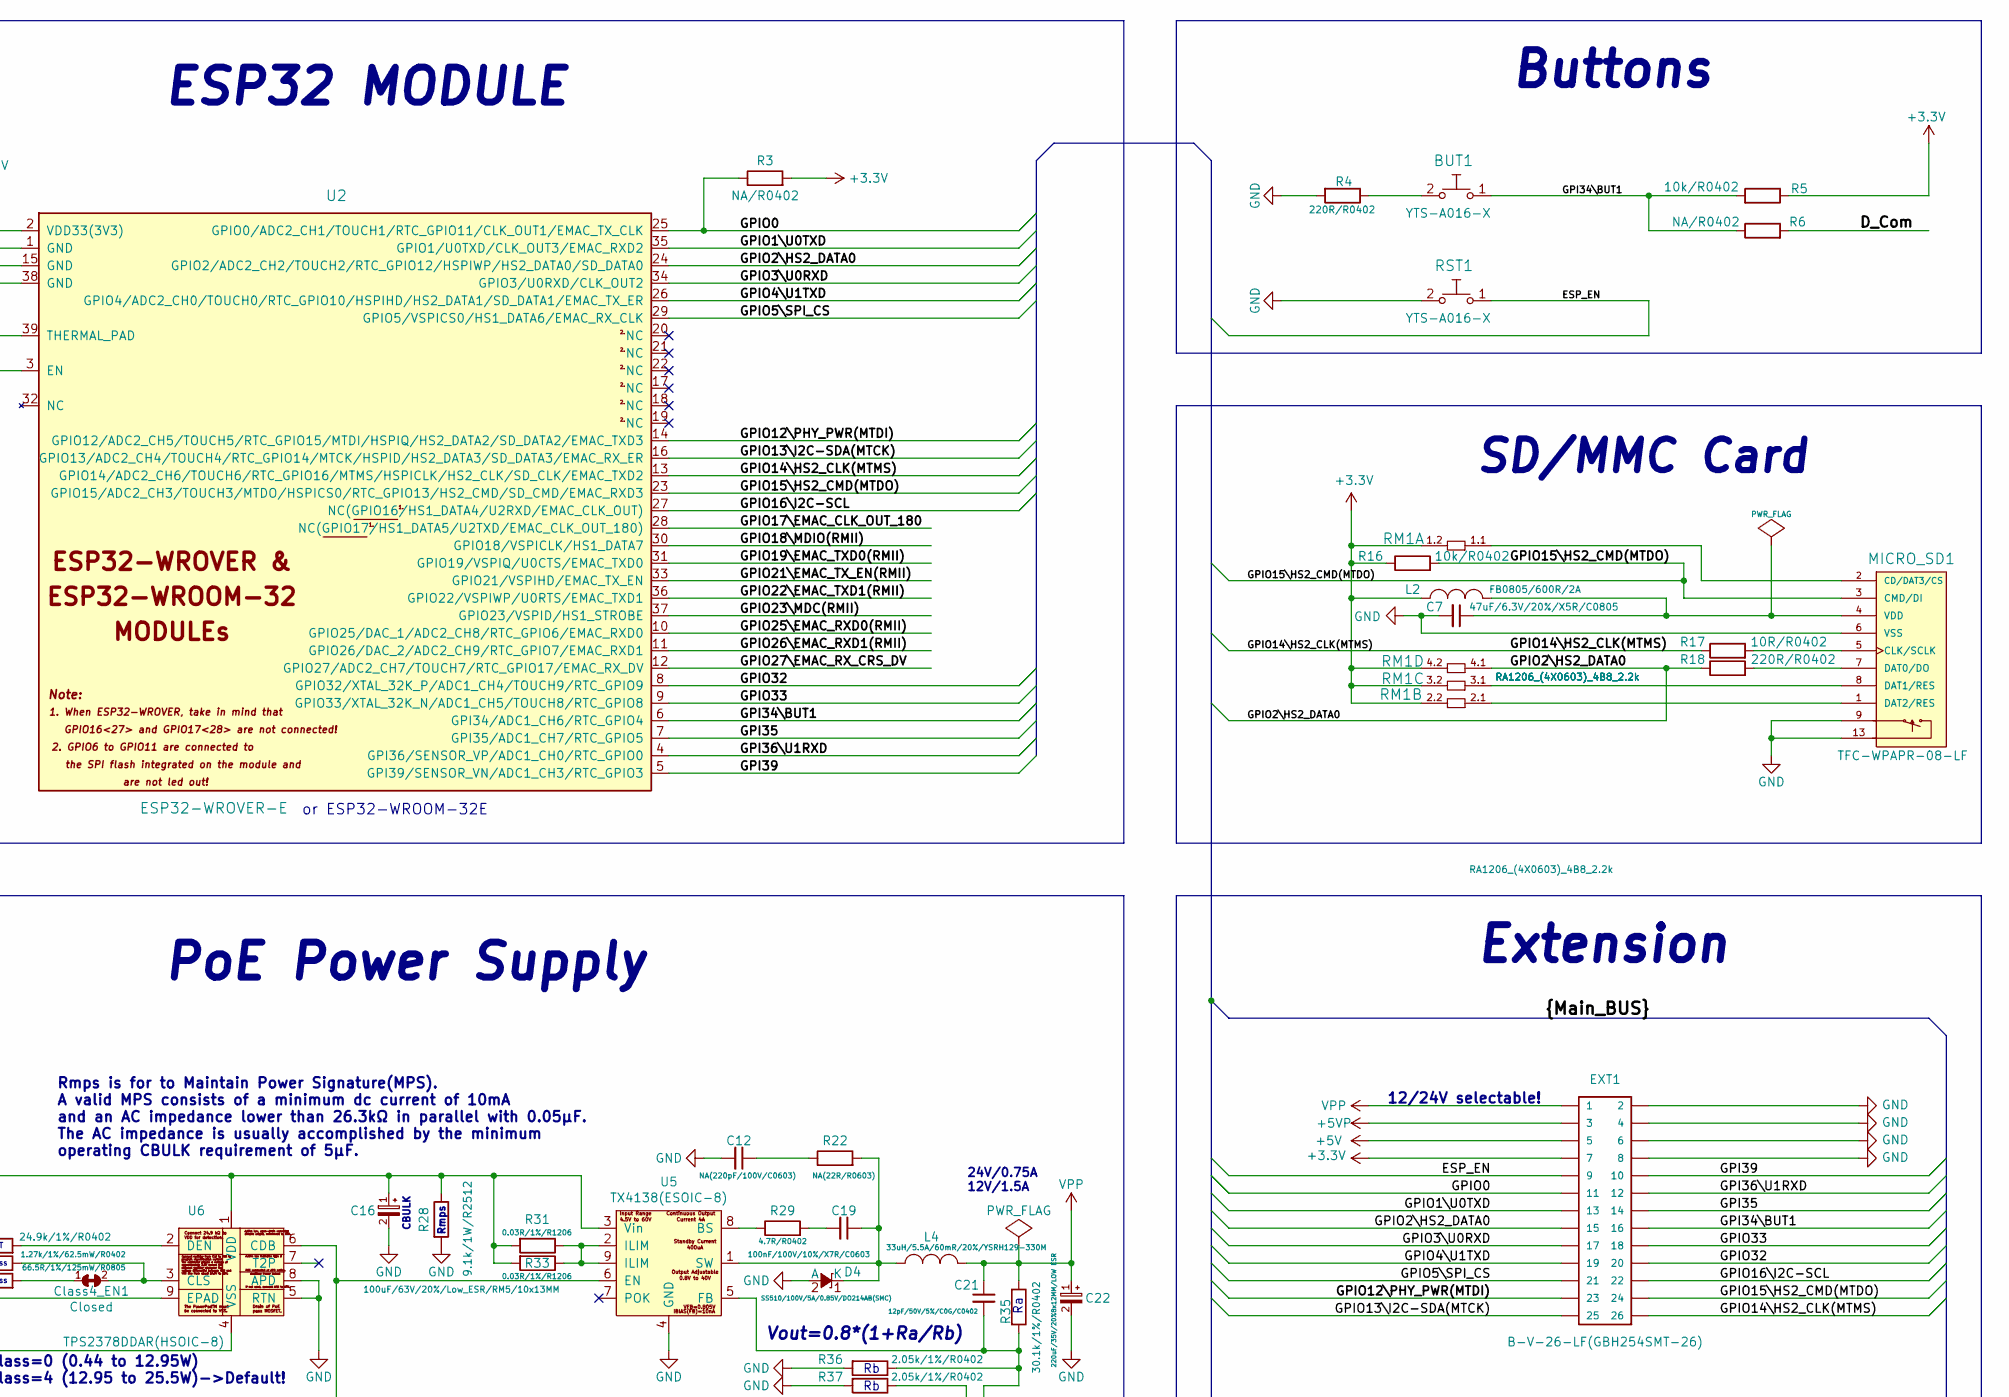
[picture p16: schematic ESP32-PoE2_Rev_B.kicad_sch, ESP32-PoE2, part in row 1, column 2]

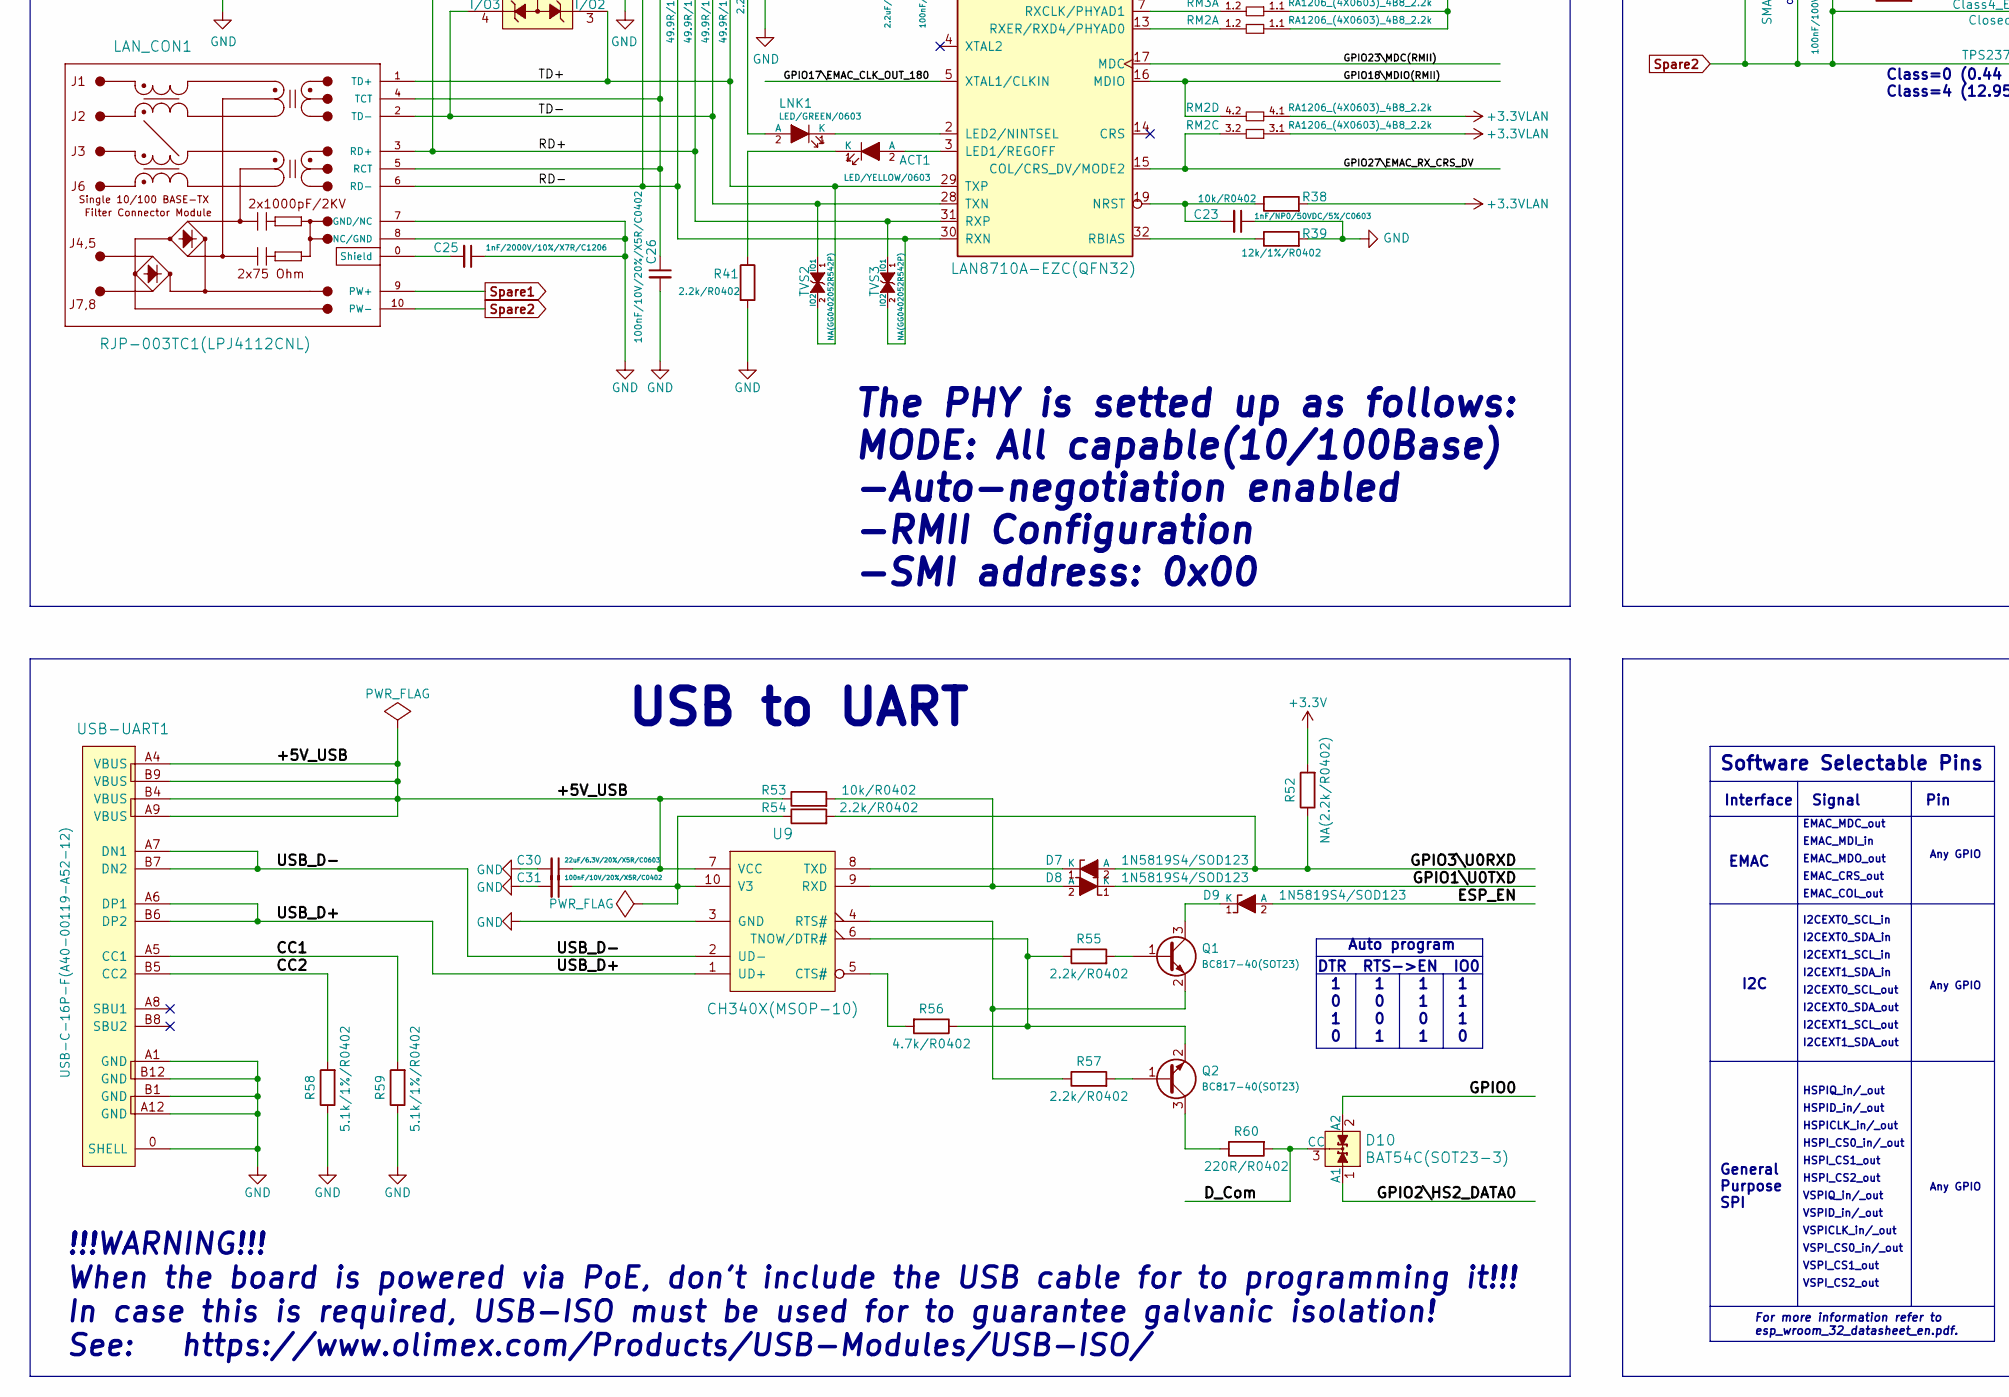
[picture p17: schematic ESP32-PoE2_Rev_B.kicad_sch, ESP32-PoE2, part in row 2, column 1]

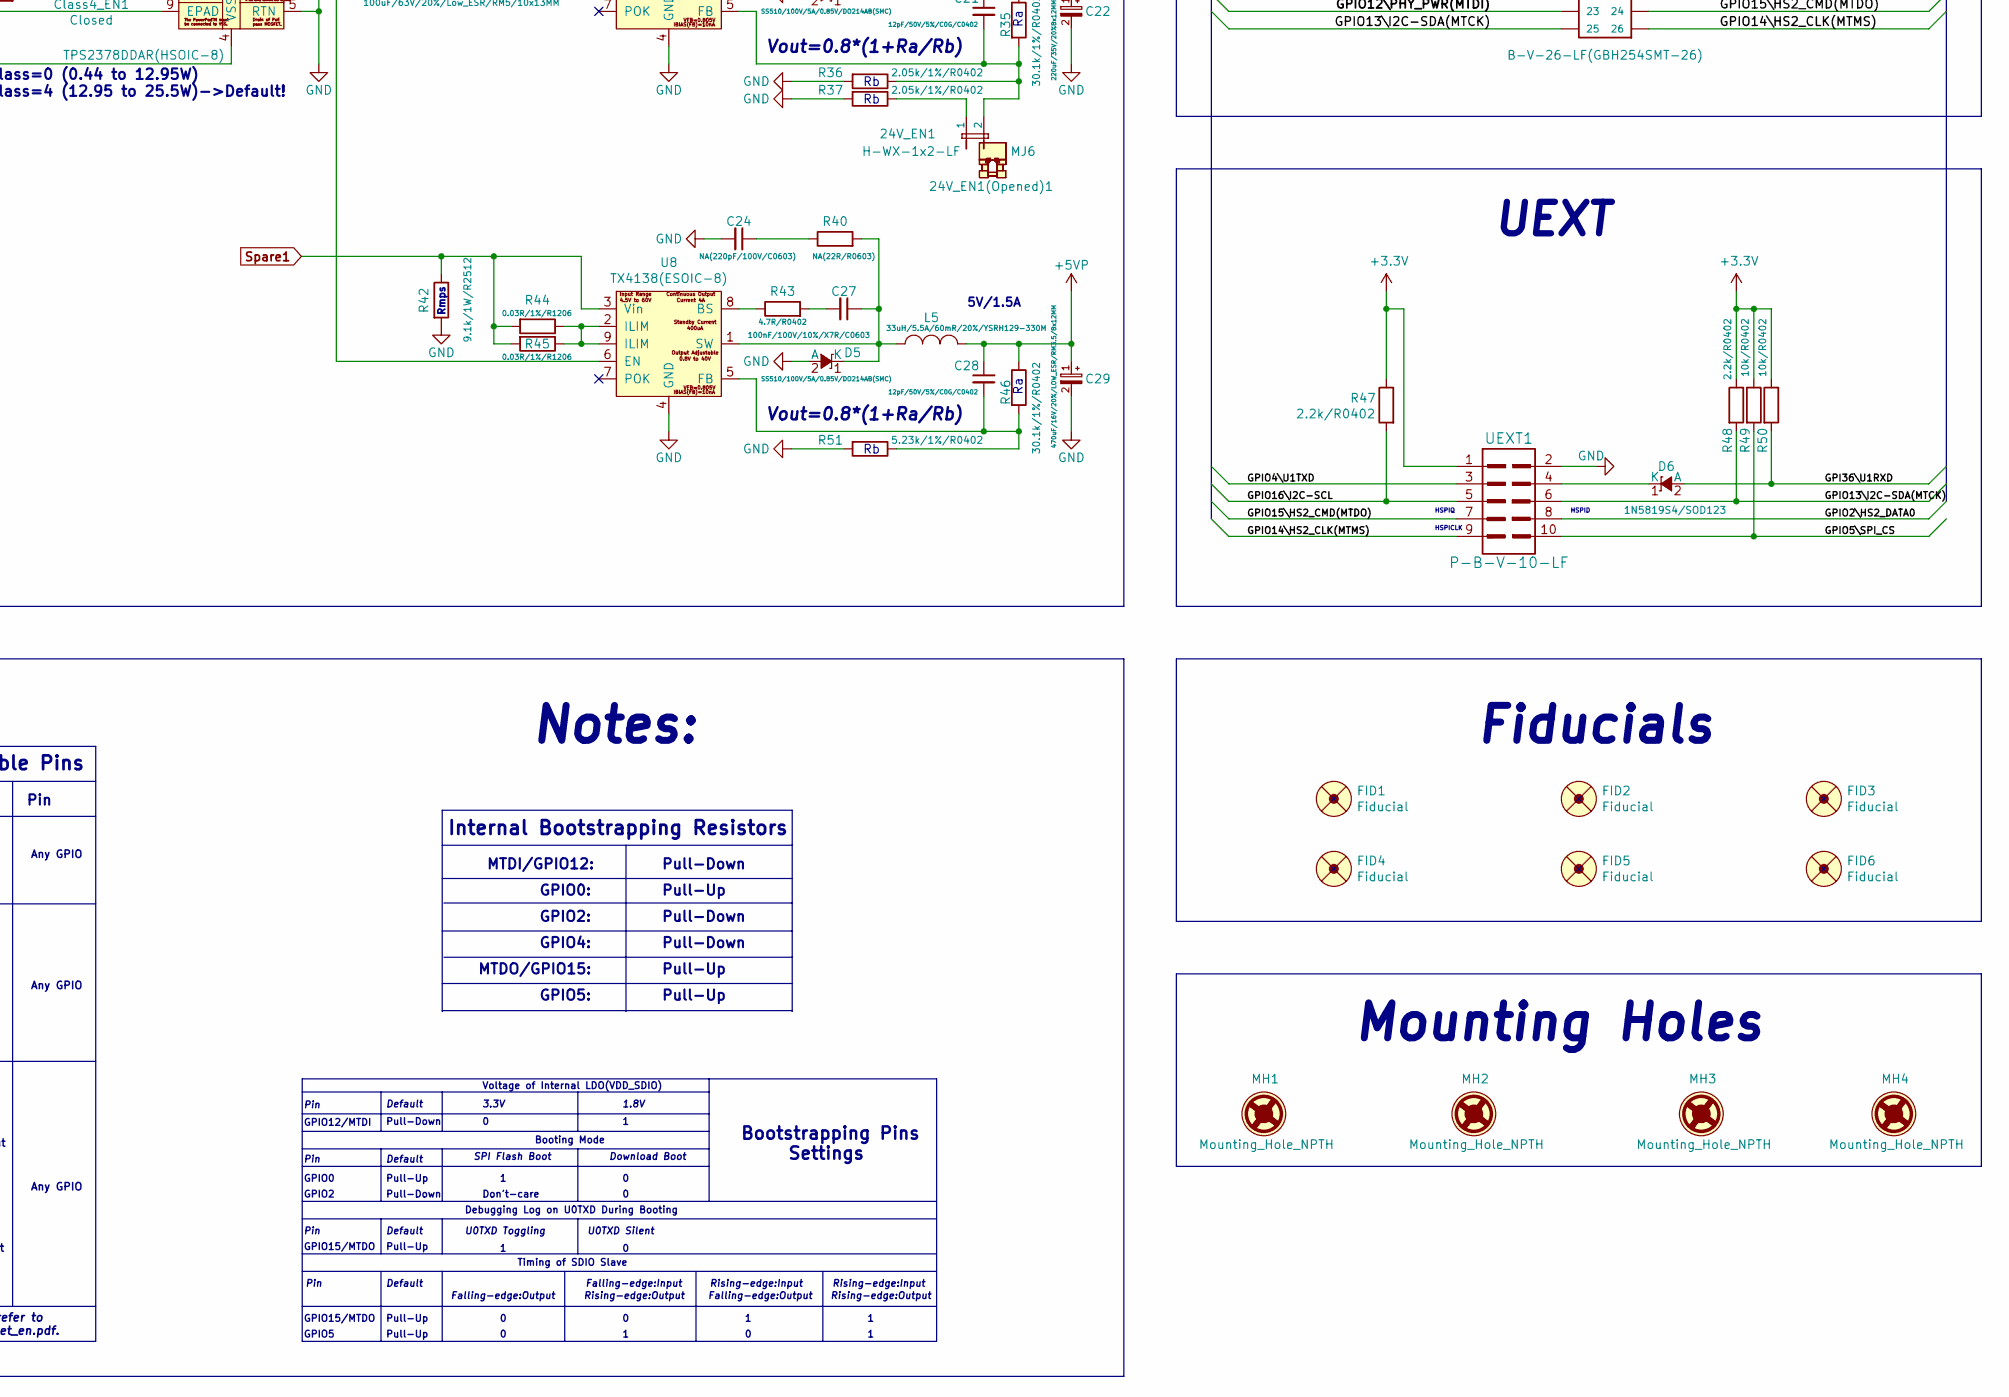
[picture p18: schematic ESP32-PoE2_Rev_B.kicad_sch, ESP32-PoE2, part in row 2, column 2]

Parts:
24V_EN1: H-WX-1x2-LF; HN1x2(SMD)_H-WX-1x2-LF
24V_EN1(Opened)1: MJ6
ACT1: LED/YELLOW/0603; LED_0603_KA
BAT1: DW02S; LIPO_BAT_VERTICAL_DW02S
BAT_SENS_E1: Opened; SJ
BUT1: YTS-A016-X
C1, C3, C6, C9, C11, C13, C30: 22uF/6.3V/20%/X5R/C0603; C_0603_5MIL_DWS
C2: 1nF/50V/10%/X7R/C0402; C_0402_5MIL_DWS
C4, C7: 47uF/6.3V/20%/X5R/C0805; C_0805_5MIL_DWS
C5: 1uF/6.3V/10%/X5R/C0402; C_0402_5MIL_DWS
C8, C10, C14, C15, C18, C26, C31: 100nF/10V/20%/X5R/C0402; C_0402_5MIL_DWS
C12, C24: NA(220pF/100V/C0603); C_0603_5MIL_DWS
C16: 100uF/63V/20%/Low_ESR/RM5/10x13MM; CPOL-RM5mm_10.0x16.0mm_PTH
C17: 2.2uF/6.3V/20%/X5R/C0402; C_0402_5MIL_DWS
C19, C20, C27: 100nF/100V/10%/X7R/C0603; C_0603_5MIL_DWS
C21, C28: 12pF/50V/5%/C0G/C0402; C_0402_5MIL_DWS
C22: 220uF/35V/20%8x12MM/LOW ESR; CPOL-RM3.5mm_8.0x11.5mm_PTH
C23: 1nF/NP0/50VDC/5%/C0603; C_0603_5MIL_DWS
C25: 1nF/2000V/10%/X7R/C1206; C_1206_5MIL_DWS_ISO
C29: 470uF/16V/20%/LOW_ESR/RM3.5/8x12MM; CPOL-RM3.5mm_8.0x11.5mm_PTH
CHRG1: LED/YELLOW/0603; LED_0603_KA
Class4_EN1: Closed; SJ_Closed
D1, D2: 1N5822/SS34/SMA; SMA-KA
D3: SMAJ58A/SMA; SMA-KA
D4, D5: SS510/100V/5A/0.85V/DO214AB(SMC); DO214AB(SMC)_1(K)-2(A)
D6, D7, D8, D9: 1N5819S4/SOD123; SOD-123_1C-2A_KA
D10: BAT54C(SOT23-3); SOT23-3
EXT1: B-V-26-LF(GBH254SMT-26); GBH-254-SMT-26
FET1, FET2, FET3: WPM2015-3/TR; SOT23
FID1, FID2, FID3: Fiducial; Fiducial1x3_Paste
FID4, FID5, FID6: Fiducial; Fiducial1x3
L1: 2.2uH/1.5A/DCR=72mR/20%/3.00x3.00x1.50mm/CD32(NR3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; CD32
L2, L3: FB0805/600R/2A; L_0805_5MIL_DWS
L4, L5: 33uH/5.5A/60mR/20%/YSRH129-330M; HSMRH129_12.0x12.5x9.5(max)
LAN_CON1: RJP-003TC1(LPJ4112CNL)
LNK1: LED/GREEN/0603; LED_0603_KA
MH1, MH2, MH3, MH4: Mounting_Hole_NPTH; Mounting_Hole_Drill-3.3mm_Clerance-7mm
MICRO_SD1: TFC-WPAPR-08-LF; TFC-WPAPR-08
PWR1: LED/RED/0603; LED_0603_KA
Q1, Q2: BC817-40(SOT23); SOT23
R1, R7: 470k/R0402; R_0402_5MIL_DWS
R2: 47k/R0402; R_0402_5MIL_DWS
R3, R6: NA/R0402; R_0402_5MIL_DWS
R4, R18, R60: 220R/R0402; R_0402_5MIL_DWS
R5, R9, R12, R15, R16, R20, R38, R49, R50, R53: 10k/R0402; R_0402_5MIL_DWS
R8: 100k/R0402; R_0402_5MIL_DWS
R10, R13, R27, R41, R47, R48, R54, R55, R57: 2.2k/R0402; R_0402_5MIL_DWS
R11: 220k/R0402; R_0402_5MIL_DWS
R14: 49.9k/1%/R0402; R_0402_5MIL_DWS
R17, R19: 10R/R0402; R_0402_5MIL_DWS
R21: 1k/R0402; R_0402_5MIL_DWS
R22, R40: NA(22R/R0603); R_0603_5MIL_DWS
R23, R24, R25, R26: 49.9R/1%/R0402; R_0402_5MIL_DWS
R28, R42: 9.1k/1W/R2512; R_2512_MM_DWS
R29, R43: 4.7R/R0402; R_0402_5MIL_DWS
R30: 24.9k/1%/R0402; R_0402_5MIL_DWS
R31, R33, R44, R45: 0.03R/1%/R1206; R_1206_5MIL_DWS
R32: 1.27k/1%/62.5mW/R0402; R_0402_5MIL_DWS
R34: 66.5R/1%/125mW/R0805; R_0805_5MIL_DWS
R35, R46: 30.1k/1%/R0402; R_0402_5MIL_DWS
R36, R37: 2.05k/1%/R0402; R_0402_5MIL_DWS
R39: 12k/1%/R0402; R_0402_5MIL_DWS
R51: 5.23k/1%/R0402; R_0402_5MIL_DWS
R52: NA(2.2k/R0402); R_0402_5MIL_DWS
R56: 4.7k/R0402; R_0402_5MIL_DWS
R58, R59: 5.1k/1%/R0402; R_0402_5MIL_DWS
RM1, RM2, RM3: RA1206_(4X0603)_4B8_2.2k; R_MATRIX_4
RST1: YTS-A016-X
T1: LMUN2211LT1G(SOT-23); SOT23
TVS1: ESDS314DBVR(SOT-23-5); SOT-23-5
TVS2, TVS3: NA(GG0402052R542P); D_0402_5MIL_DWS
U1: SY8089AAAC(SOT23-5); SOT-23-5
U2: ESP32-WROVER-E; ESP32-WROVER(WROOM)-UNIVERSAL_MODULE
U3: BL4054B-42TPRN(SOT23-5); SOT-23-5
U4: SN74LVC1G04DBVR(SOT23-5); SOT-23-5
U5, U8: TX4138(ESOIC-8); ESOIC-8
U6: TPS2378DDAR(HSOIC-8); ESOIC-8
U7: LAN8710A-EZC(QFN32); QFN32_EP(33)_5.00x5.00x0.90mm_Pitch_0.50mm
U9: CH340X(MSOP-10); MSOP-10_Pitch-0.5mm_3.00x3.00x1.00mm
UEXT1: P-B-V-10-LF; GBH-254-SMT-10
USB-UART1: USB-C-16P-F(A40-00119-A52-12); USB2.0_TYPE-C(A40-00119-A52-12)_Paste

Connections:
+3.3V: C1.1, C4.1, C9.1, EXT1.7, FET3.2, L1.2, L2.1, R3.2, R5.1, R9.1, R11.2, R16.1, R20.1, R47.1, R48.1, R49.1, R50.1, R52.2, RM1.1.2, RM1.2.2, RM1.3.2, RM1.4.2, U2.2 (VDD33(3V3)), UEXT1.1
+3.3VLAN: C8.2, C10.1, C11.1, FET3.3, L3.1, R38.2, RM2.2.1, RM2.3.1, RM2.4.1, RM3.3.1, RM3.4.1, U4.5 (VCC), U7.12 (VDDIO)
+5V: C6.1, CHRG1.2 (A), D1.2 (A), D2.1 (K), EXT1.5, FET1.2, FET2.1, PWR1.2 (A), R2.1, R12.1, U3.4 (VCC)
+5VP: C28.1, C29.1 (+), D2.2 (A), EXT1.3, FET1.1, L5.2, R46.1
/+5V_USB: C30.1, FET1.3, R53.1, U9.7 (VCC), USB-UART1.A4 (VBUS), USB-UART1.A9 (VBUS), USB-UART1.B4 (VBUS), USB-UART1.B9 (VBUS)
/CC1: R59.2, USB-UART1.A5 (CC1)
/CC2: R58.2, USB-UART1.B5 (CC2)
/D_Com: D10.3 (CC), R6.2, R60.2
/ESP_EN: C5.1, D9.2 (A), EXT1.9, R9.2, RST1.1, U2.3 (EN)
/GPI34\BUT1: BUT1.1, EXT1.16, R5.2, R6.1, U2.6 (GPI34/ADC1_CH6/RTC_GPIO4)
/GPI35: BAT_SENS_E1.1, EXT1.14, U2.7 (GPI35/ADC1_CH7/RTC_GPIO5)
/GPI36\U1RXD: D6.2 (A), EXT1.12, R50.2, U2.4 (GPI36/SENSOR_VP/ADC1_CH0/RTC_GPIO0)
/GPI39: EXT1.10, R2.2, R8.1, U2.5 (GPI39/SENSOR_VN/ADC1_CH3/RTC_GPIO3)
/GPIO0: D10.2 (A2), EXT1.11, R3.1, U2.25 (GPIO0/ADC2_CH1/TOUCH1/RTC_GPIO11/CLK_OU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), U4.2 (A)
/GPIO1\U0TXD: D8.1 (K), EXT1.13, U2.35 (GPIO1/U0TXD/CLK_OUT3/EMAC_RXD2)
/GPIO2\HS2_DATA0: D10.1 (A1), EXT1.15, R18.1, RM1.4.1, U2.24 (GPIO2/ADC2_CH2/TOUCH2/RTC_GPIO12/HSPIWP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), UEXT1.8
/GPIO3\U0RXD: D7.2 (A), EXT1.17, R52.1, R54.2, U2.34 (GPIO3/U0RXD/CLK_OUT2)
/GPIO4\U1TXD: EXT1.19, U2.26 (GPIO4/ADC2_CH0/TOUCH0/RTC_GPIO10/HSPIHD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), UEXT1.3
/GPIO5\SPI_CS: EXT1.21, R49.2, U2.29 (GPIO5/VSPICS0/HS1_DATA6/EMAC_RX_CLK), UEXT1.10
/GPIO12\PHY_PWR(MTDI): EXT1.23, T1.1 (B), U2.14 (GPIO12/ADC2_CH5/TOUCH5/RTC_GPIO15/MTDI/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)
/GPIO13\I2C-SDA(MTCK): EXT1.25, R48.2, U2.16 (GPIO13/ADC2_CH4/TOUCH4/RTC_GPIO14/MTCK/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), UEXT1.6
/GPIO14\HS2_CLK(MTMS): EXT1.26, R17.1, U2.13 (GPIO14/ADC2_CH6/TOUCH6/RTC_GPIO16/MTMS/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), UEXT1.9
/GPIO15\HS2_CMD(MTDO): EXT1.24, MICRO_SD1.3 (CMD/DI), R16.2, U2.23 (GPIO15/ADC2_CH3/TOUCH3/MTDO/HSPICS0/RTC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), UEXT1.7
/GPIO16\I2C-SCL: EXT1.22, R19.2, R47.2, U2.27 (NC(GPIO16/HS1_DATA4/U2RXD/EMAC_CLK_OUT)), UEXT1.5
/GPIO17\EMAC_CLK_OUT_180: U2.28 (NC(GPIO17/HS1_DATA5/U2TXD/EMAC_CLK_OUT_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), U4.4 (Y), U7.5 (XTAL1/CLKIN)
/GPIO18\MDIO(RMII): RM2.4.2, U2.30 (GPIO18/VSPICLK/HS1_DATA7), U7.16 (MDIO)
/GPIO19\EMAC_TXD0(RMII): U2.31 (GPIO19/VSPIQ/U0CTS/EMAC_TXD0), U7.22 (TXD0)
/GPIO21\EMAC_TX_EN(RMII): U2.33 (GPIO21/VSPIHD/EMAC_TX_EN), U7.21 (TXEN)
/GPIO22\EMAC_TXD1(RMII): U2.36 (GPIO22/VSPIWP/U0RTS/EMAC_TXD1), U7.23 (TXD1)
/GPIO23\MDC(RMII): U2.37 (GPIO23/VSPID/HS1_STROBE), U7.17 (MDC)
/GPIO25\EMAC_RXD0(RMII): RM3.3.2, U2.10 (GPIO25/DAC_1/ADC2_CH8/RTC_GPIO6/EMAC_RX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), U7.11 (RXD0/MODE0)
/GPIO26\EMAC_RXD1(RMII): RM3.4.2, U2.11 (GPIO26/DAC_2/ADC2_CH9/RTC_GPIO7/EMAC_RX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), U7.10 (RXD1/MODE1)
/GPIO27\EMAC_RX_CRS_DV: RM2.3.2, U2.12 (GPIO27/ADC2_CH7/TOUCH7/RTC_GPIO17/EMAC_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), U7.15 (COL/CRS_DV/MODE2)
/GPIO32: EXT1.20, U2.8 (GPIO32/XTAL_32K_P/ADC1_CH4/TOUCH9/RTC_G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)
/GPIO33: EXT1.18, R19.1, U2.9 (GPIO33/XTAL_32K_N/ADC1_CH5/TOUCH8/RTC_G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)
/RD+: LAN_CON1.3 (RD+), R24.2, TVS1.5 (I/O4), TVS3.1 (IO1), U7.31 (RXP)
/RD-: LAN_CON1.6 (RD-), R23.2, TVS1.1 (I/O1), TVS3.2 (IO2), U7.30 (RXN)
/TD+: LAN_CON1.1 (TD+), R26.2, TVS1.3 (I/O2), TVS2.2 (IO2), U7.29 (TXP)
/TD-: LAN_CON1.2 (TD-), R25.2, TVS1.4 (I/O3), TVS2.1 (IO1), U7.28 (TXN)
/USB_D+: U9.1 (UD+), USB-UART1.A6 (DP1), USB-UART1.B6 (DP2)
/USB_D-: U9.2 (UD-), USB-UART1.A7 (DN1), USB-UART1.B7 (DN2)
GND: BAT1.2, C1.2, C2.2, C3.2, C4.2, C5.2, C6.2, C7.2, C8.1, C10.2, C11.2, C12.2, C13.2, C14.2, C15.2, C16.2 (-), C17.2, C18.2, C22.2 (-), C23.1, C24.2, C25.1, C26.2, C29.2 (-), C30.2, C31.2, D4.2 (A), D5.2 (A), EXT1.2, EXT1.4, EXT1.6, EXT1.8, LAN_CON1.7 (GND/NC), LAN_CON1.8 (NC/GND), MICRO_SD1.6 (VSS), MICRO_SD1.9, MICRO_SD1.10, MICRO_SD1.11, MICRO_SD1.12, MICRO_SD1.13, R4.2, R7.2, R8.2, R12.2, R13.2, R14.2, R15.2, R28.2, R36.2, R37.2, R39.2, R41.2, R42.2, R51.2, R58.1, R59.1, RM2.1.1, RM3.1.1, RM3.2.1, RST1.2, T1.2 (E), TVS1.2 (GND), U1.2 (GND), U2.1 (GND), U2.15 (GND), U2.38 (GND), U2.39 (THERMAL_PAD), U3.2 (GND), U4.3 (GND), U5.4 (GND), U6.5 (RTN), U6.8 (APD), U7.24 (TXD2), U7.25 (TXD3), U7.33 (GND), U8.4 (GND), U9.3 (GND), UEXT1.2, USB-UART1.0 (SHELL), USB-UART1.A1 (GND), USB-UART1.A12 (GND), USB-UART1.B1 (GND), USB-UART1.B12 (GND)
unnamed: 24V_EN1.1, R37.1
unnamed: ACT1.2 (A), U7.3 (LED1/REGOFF)
unnamed: ACT1.1 (K), R41.1
unnamed: BAT_SENS_E1.2, C2.1, R1.2, R7.1
unnamed: BUT1.2, R4.1
unnamed: C9.2, FET3.1, R20.2, R21.1
unnamed: C12.1, R22.1
unnamed: C19.2, R29.2
unnamed: C24.1, R40.1
unnamed: C27.2, R43.2
unnamed: CHRG1.1 (K), R10.1
unnamed: Class4_EN1.1, R34.2
unnamed: C3.1, D1.1 (K), FET2.2, U1.1 (EN), U1.4 (IN)
unnamed: C19.1, D4.1 (K), L4.1, R22.2, U5.1 (SW)
unnamed: C27.1, D5.1 (K), L5.1, R40.2, U8.1 (SW)
unnamed: D6.1 (K), UEXT1.4
unnamed: D7.1 (K), U9.8 (TXD)
unnamed: D8.2 (A), R53.2, U9.9 (RXD)
unnamed: D9.1 (K), Q1.3 (C)
unnamed: C13.1, C14.1, C15.1, C26.1, L3.2, LAN_CON1.4 (TCT), LAN_CON1.5 (RCT), R23.1, R24.1, R25.1, R26.1, R27.1, U7.1 (VDD2A), U7.27 (VDD1A)
unnamed: C25.2, LAN_CON1.0 (Shield)
unnamed: LNK1.2 (A), R27.2
unnamed: LNK1.1 (K), U7.2 (LED2/NINTSEL)
unnamed: MICRO_SD1.2 (CD/DAT3/CS), RM1.1.1
unnamed: MICRO_SD1.5 (CLK/SCLK), R17.2
unnamed: MICRO_SD1.7 (DAT0/DO), R18.2
unnamed: MICRO_SD1.8 (DAT1/RES), RM1.3.1
unnamed: MICRO_SD1.1 (DAT2/RES), RM1.2.1
unnamed: C7.1, L2.2, MICRO_SD1.4 (VDD)
unnamed: PWR1.1 (K), R13.1
unnamed: Q1.1 (B), R55.2
unnamed: Q1.2 (E), R57.1, U9.4 (RTS#)
unnamed: Q2.1 (B), R57.2
unnamed: Q2.3 (C), R60.1
unnamed: Q2.2 (E), R55.1, R56.1, U9.6 (TNOW/DTR#)
unnamed: R31.1, R33.1, U5.2 (ILIM), U5.9 (ILIM)
unnamed: R44.1, R45.1, U8.2 (ILIM), U8.9 (ILIM)
unnamed: R21.2, T1.3 (C)
unnamed: R11.1, R14.1, U1.5 (FB)
unnamed: L1.1, U1.3 (LX)
unnamed: R10.2, U3.1 (CHRGb)
unnamed: R15.1, U3.5 (PROG)
unnamed: R29.1, U5.8 (BS)
unnamed: U5.6 (EN), U6.6 (CDB), U8.6 (EN)
unnamed: 24V_EN1.2, C21.2, R35.2, R36.1, U5.5 (FB)
unnamed: Class4_EN1.2, R32.1, U6.3 (CLS)
unnamed: R30.2, U6.2 (DEN)
unnamed: C23.2, R38.1, U7.19 (NRST)
unnamed: R39.1, U7.32 (RBIAS)
unnamed: RM3.1.2, U7.7 (RXCLK/PHYAD1)
unnamed: RM2.2.2, U7.9 (RXD2/RMIISEL)
unnamed: RM3.2.2, U7.8 (RXD3/PHYAD2)
unnamed: RM2.1.2, U7.13 (RXER/RXD4/PHYAD0)
unnamed: C17.1, C18.1, U7.6 (VDDCR)
unnamed: R43.1, U8.8 (BS)
unnamed: C28.2, R46.2, R51.1, U8.5 (FB)
unnamed: R56.2, U9.5 (CTS#)
unnamed: C31.1, R54.1, U9.10 (V3)
Spare1: C16.1 (+), C20.1, D3.1 (K), LAN_CON1.9 (PW+), R28.1, R30.1, R31.2, R33.2, R42.1, R44.2, R45.2, U5.3 (Vin), U6.1 (VDD), U8.3 (Vin)
Spare2: C20.2, D3.2 (A), LAN_CON1.10 (PW-), R32.2, R34.1, U6.4 (VSS), U6.9 (EPAD)
VBAT: BAT1.1, FET2.3, R1.1, U3.3 (VBAT)
VPP: C21.1, C22.1 (+), EXT1.1, L4.2, R35.1

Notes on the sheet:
VSPI_CS0_in/_out
U0TXD Silent
CHARGING
Software Selectable Pins
Buttons
Voltage of Internal LDO(VDD_SDIO)
GPIO4:
Pull-Down
3.3V
EMAC_CRS_out
Pull-Up
GPIO0:
Vout=0.8*(1+Ra/Rb)
VSPID_in/_out
24V/0.75A 12V/1.5A
Download Boot
SD/MMC Card
Rmps
Default
EMAC_COL_out
Signal
Rising-edge:Input
I2CEXT0_SDA_in
Internal Bootstrapping Resistors
Auto program
EMAC_MDI_in
Extension
RDET
Class=0 (0.44 to 12.95W) Class=4 (12.95 to 25.5W)->Default!
Any GPIO
Rising-edge:Output
IBAT = 1000/Rprog = 100mA
Rclass
General Purpose SPI
Power Supply
HSPI_CS1_out
HSPID
UEXT
Pin
GPIO2:

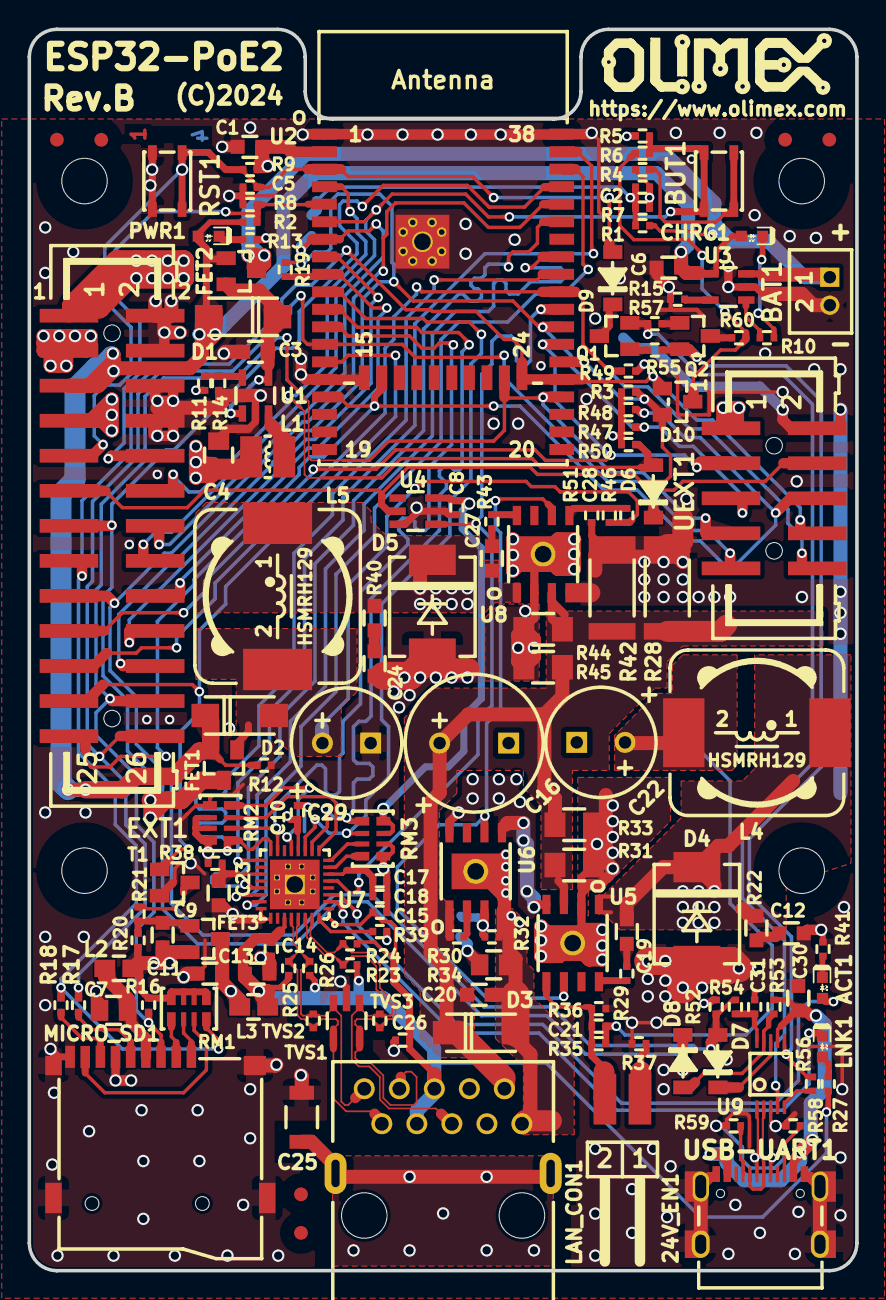
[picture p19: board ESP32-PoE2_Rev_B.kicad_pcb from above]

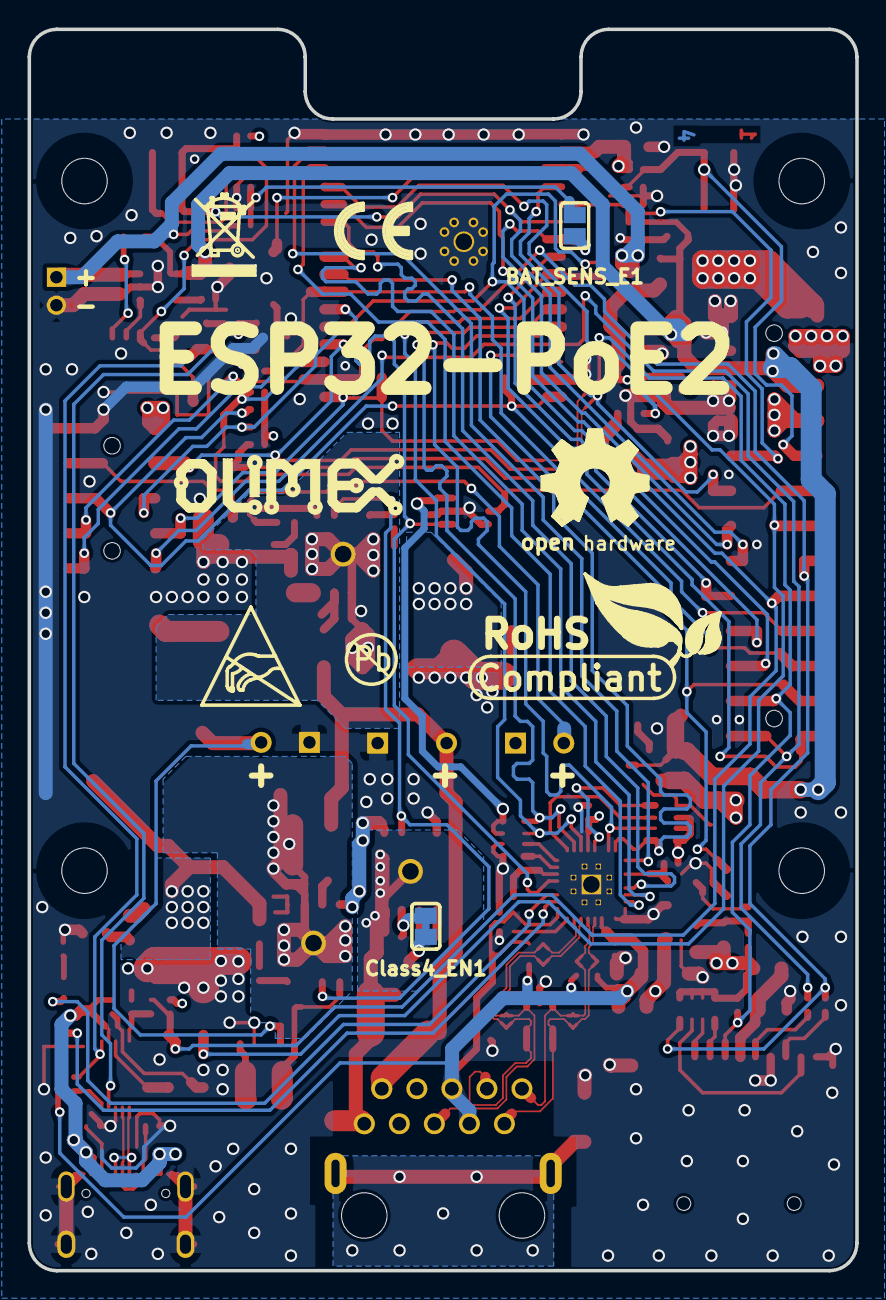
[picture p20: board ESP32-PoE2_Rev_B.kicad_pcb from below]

Board: 4 copper layers, 60.0 x 90.0 mm, 161 parts (9 on the bottom side), 104 nets.

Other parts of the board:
CE: CE_Sign
Logo_OLIMEX_TB: Logo_OLIMEX_TB
Logo_Olimex: OLIMEX_LOGO_TB
Sign_Antistatic: Sign_Antistatic
Sign_OSHW_8x8: Sign_OSHW_8x8
Sign_PB-Free: Sign_PB-Free
Sign_RecycleBin_1: Sign_RecycleBin_1
Sign_RoHS_1: Sign_RoHS_1

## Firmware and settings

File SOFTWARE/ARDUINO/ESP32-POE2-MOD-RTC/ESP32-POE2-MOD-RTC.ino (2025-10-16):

/*
   Olimex ESP32-POE2 + MOD-RTC (PCF8563T) Arduino IDE Demo
   ------------------------------------------------------
   ESP32-POE2 uses WROVER module, make sure to select PSRAM enabled (WROVER) from Tools

   After downloading to the board, go to Tools -> Serial Monitor and set baud to 115200
   
   Features:
     • Continuously reads and prints current date/time from the RTC every 1s.
     • Short press BUT1 → Syncs RTC with sketch compile time.
     • Long press BUT1 (5 sec) → Enter manual time setup via Serial.
   ------------------------------------------------------
   Hardware connections:
     SDA = GPIO13
     SCL = GPIO33
     BUT1 = GPIO34 (input only, active LOW)
*/

#include <Wire.h>

#define PCF8563_ADDR 0x51
#define SDA_PIN 13
#define SCL_PIN 33
#define BUTTON_PIN 34
#define LONG_PRESS_MS 5000
#define BUTTON_POLL_MS 50
#define PRINT_INTERVAL_MS 1000

uint8_t dec2bcd(uint8_t val) { return ((val / 10) << 4) | (val % 10); }
uint8_t bcd2dec(uint8_t val) { return (val & 0x0F) + ((val >> 4) * 10); }

unsigned long lastButtonPoll = 0;
unsigned long lastPrintTime = 0;
unsigned long buttonPressedTime = 0;
bool buttonHeld = false;

void setup() {
  Serial.begin(115200);
  while (!Serial);

  Serial.println("\n=== Olimex ESP32-POE-2 + MOD-RTC (PCF8563) Demo ===");

  pinMode(BUTTON_PIN, INPUT);
  Wire.begin(SDA_PIN, SCL_PIN);

  Wire.beginTransmission(PCF8563_ADDR);
  if (Wire.endTransmission() != 0) {
    Serial.println("⚠️  PCF8563 not detected at address 0x51!");
    while (true);
  }
  Serial.println("RTC detected successfully.\n");
}

void loop() {
  unsigned long now = millis();

  // --- Non-blocking button handler (every 50 ms) ---
  if (now - lastButtonPoll >= BUTTON_POLL_MS) {
    handleButton();
    lastButtonPoll = now;
  }

  // --- Non-blocking RTC print (every 1 second) ---
  if (now - lastPrintTime >= PRINT_INTERVAL_MS) {
    printRTC();
    lastPrintTime = now;
  }
}

// ---------------------------------------------------------------------------
// BUTTON HANDLER
// ---------------------------------------------------------------------------
void handleButton() {
  int btnState = digitalRead(BUTTON_PIN);

  if (btnState == LOW) { // pressed
    if (buttonPressedTime == 0)
      buttonPressedTime = millis();

    if (!buttonHeld && (millis() - buttonPressedTime > LONG_PRESS_MS)) {
      buttonHeld = true;
      Serial.println("\n=== LONG PRESS detected ===");
      manualSetRTC();
    }
  } else { // released
    if (buttonPressedTime > 0 && !buttonHeld) {
      unsigned long pressDuration = millis() - buttonPressedTime;
      if (pressDuration < LONG_PRESS_MS && pressDuration > 30) {
        Serial.println("\n=== SHORT PRESS detected ===");
        setRTCtoCompileTime();
      }
    }
    buttonPressedTime = 0;
    buttonHeld = false;
  }
}

// ---------------------------------------------------------------------------
// SET RTC TO COMPILE TIME
// ---------------------------------------------------------------------------
void setRTCtoCompileTime() {
  const char *timeStr = __TIME__;
  const char *dateStr = __DATE__;

  uint8_t hour = (timeStr[0] - '0') * 10 + (timeStr[1] - '0');
  uint8_t min  = (timeStr[3] - '0') * 10 + (timeStr[4] - '0');
  uint8_t sec  = (timeStr[6] - '0') * 10 + (timeStr[7] - '0');

  char monthStr[4];
  memcpy(monthStr, dateStr, 3);
  monthStr[3] = '\0';
  const char *months = "JanFebMarAprMayJunJulAugSepOctNovDec";
  uint8_t mon = (strstr(months, monthStr) - months) / 3 + 1;
  uint8_t day = (dateStr[4] == ' ') ? (dateStr[5] - '0') : ((dateStr[4] - '0') * 10 + (dateStr[5] - '0'));
  uint16_t year = atoi(dateStr + 7) - 2000;

  writeRTC(sec, min, hour, day, mon, year);
  Serial.printf("RTC synced to compile time: %04u-%02u-%02u %02u:%02u:%02u\n\n",
                2000 + year, mon, day, hour, min, sec);
}

// ---------------------------------------------------------------------------
// MANUAL TIME SETUP VIA SERIAL
// ---------------------------------------------------------------------------
void manualSetRTC() {
  Serial.println("Enter new date and time in the following format:");
  Serial.println("YYYY-MM-DD HH:MM:SS");
  Serial.print("Example: 2025-10-16 18:45:00\n> ");

  String input = "";
  unsigned long timeout = millis();
  while ((millis() - timeout) < 60000) {
    if (Serial.available()) {
      input = Serial.readStringUntil('\n');
      input.trim();
      break;
    }
  }

  if (input.length() != 19) {
    Serial.println("Invalid format or timeout. Aborting.\n");
    return;
  }

  uint16_t year = input.substring(0, 4).toInt() - 2000;
  uint8_t mon   = input.substring(5, 7).toInt();
  uint8_t day   = input.substring(8, 10).toInt();
  uint8_t hour  = input.substring(11, 13).toInt();
  uint8_t min   = input.substring(14, 16).toInt();
  uint8_t sec   = input.substring(17, 19).toInt();

  if (mon < 1 || mon > 12 || day < 1 || day > 31 || hour > 23 || min > 59 || sec > 59) {
    Serial.println("Invalid values entered. Aborting.\n");
    return;
  }

  writeRTC(sec, min, hour, day, mon, year);
  Serial.printf("RTC manually set to: %04u-%02u-%02u %02u:%02u:%02u\n\n",
                2000 + year, mon, day, hour, min, sec);
}

// ---------------------------------------------------------------------------
// WRITE TO RTC
// ---------------------------------------------------------------------------
void writeRTC(uint8_t sec, uint8_t min, uint8_t hour, uint8_t day, uint8_t mon, uint16_t year) {
  Wire.beginTransmission(PCF8563_ADDR);
  Wire.write(0x02);
  Wire.write(dec2bcd(sec) & 0x7F);
  Wire.write(dec2bcd(min) & 0x7F);
  Wire.write(dec2bcd(hour) & 0x3F);
  Wire.write(dec2bcd(day) & 0x3F);
  Wire.write(0x00); // weekday = 0
  Wire.write(dec2bcd(mon) & 0x1F);
  Wire.write(dec2bcd(year));
  Wire.endTransmission();
}

// ---------------------------------------------------------------------------
// READ AND PRINT CURRENT RTC TIME
// ---------------------------------------------------------------------------
void printRTC() {
  Wire.beginTransmission(PCF8563_ADDR);
  Wire.write(0x02);
  Wire.endTransmission();

  Wire.requestFrom(PCF8563_ADDR, 7);
  if (Wire.available() < 7) return;

  uint8_t sec_bcd = Wire.read();
  uint8_t min_bcd = Wire.read();
  uint8_t hr_bcd  = Wire.read();
  uint8_t day_bcd = Wire.read();
  Wire.read(); // weekday
  uint8_t mon_bcd = Wire.read();
  uint8_t yr_bcd  = Wire.read();

  uint8_t sec = bcd2dec(sec_bcd & 0x7F);
  uint8_t min = bcd2dec(min_bcd & 0x7F);
  uint8_t hr  = bcd2dec(hr_bcd & 0x3F);
  uint8_t day = bcd2dec(day_bcd & 0x3F);
  uint8_t mon = bcd2dec(mon_bcd & 0x1F);
  uint16_t yr = 2000 + bcd2dec(yr_bcd);

  Serial.printf("%04u-%02u-%02u %02u:%02u:%02u\n", yr, mon, day, hr, min, sec);
}

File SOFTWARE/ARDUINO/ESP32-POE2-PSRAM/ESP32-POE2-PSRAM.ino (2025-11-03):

/*
  ESP32-POE2 PSRAM Demonstration
  -------------------------------------------
  This sketch:
   - Checks if PSRAM is available
   - Prints PSRAM and heap stats every 15 seconds
   - Demonstrates storing and retrieving data in PSRAM

  Tested on: OLIMEX ESP32-POE2 (ESP32-WROVER-E-N4R8)
  Board: "ESP32 Dev Module" or "OLIMEX ESP32-POE"
  Remember to enable PSRAM - Tools → PSRAM → Enabled
  Remember to select serial port of the device
*/

#define REPORT_INTERVAL 15000  // milliseconds
#define BUFFER_SIZE (1024 * 50) // 50 KB for demo

uint8_t *psramBuffer = nullptr;
unsigned long reportCounter = 0;

void printMemoryReport() {
  Serial.println("\n--------------------------------------------");
  Serial.print("Memory Report #");
  Serial.println(++reportCounter);
  Serial.println("--------------------------------------------");

  if (psramFound()) {
    Serial.println("* PSRAM detected and enabled");
    Serial.print("  Total PSRAM: ");
    Serial.print(ESP.getPsramSize() / 1024);
    Serial.println(" KB");

    Serial.print("  Free PSRAM:  ");
    Serial.print(ESP.getFreePsram() / 1024);
    Serial.println(" KB");
  } else {
    Serial.println("! PSRAM not found or not enabled");
  }

  Serial.println("\nHeap info:");
  Serial.print("  Total Heap: ");
  Serial.print(ESP.getHeapSize() / 1024);
  Serial.println(" KB");

  Serial.print("  Free Heap:  ");
  Serial.print(ESP.getFreeHeap() / 1024);
  Serial.println(" KB");

  Serial.println("--------------------------------------------\n");
}

void storeAndRetrieveDemo() {
  Serial.println("Demonstrating PSRAM data storage...");

  // Allocate buffer in PSRAM
  psramBuffer = (uint8_t *)ps_malloc(BUFFER_SIZE);
  if (psramBuffer == nullptr) {
    Serial.println("! Failed to allocate PSRAM buffer");
    return;
  }

  Serial.print("* Allocated ");
  Serial.print(BUFFER_SIZE / 1024);
  Serial.println(" KB buffer in PSRAM");

  // Fill buffer with a recognizable pattern
  for (size_t i = 0; i < BUFFER_SIZE; i++) {
    psramBuffer[i] = (i % 256);
  }
  Serial.println("* Wrote test pattern to PSRAM");

  // Show first 16 bytes
  Serial.print("  First 16 bytes: ");
  for (int i = 0; i < 16; i++) {
    Serial.printf("%02X ", psramBuffer[i]);
  }
  Serial.println();

  // Verify data
  bool valid = true;
  for (size_t i = 0; i < BUFFER_SIZE; i++) {
    if (psramBuffer[i] != (i % 256)) {
      valid = false;
      break;
    }
  }

  if (valid)
    Serial.println("* Data verified correctly in PSRAM");
  else
    Serial.println("! Data mismatch detected in PSRAM");

  // Release buffer
  free(psramBuffer);
  psramBuffer = nullptr;
  Serial.println("* PSRAM buffer released\n");
}

void setup() {
  Serial.begin(115200);
  while (!Serial) { delay(10); } // Wait for Serial Monitor
  delay(1000);

  Serial.println("\n=== ESP32-POE2 PSRAM Test ===");

  if (!psramFound()) {
    Serial.println("! PSRAM not detected. Check Tools → PSRAM → Enabled");
  } else {
    Serial.println("* PSRAM detected successfully");
  }

  // Immediate visible output before loop
  printMemoryReport();
  storeAndRetrieveDemo();
}

void loop() {
  delay(REPORT_INTERVAL);
  printMemoryReport();
  storeAndRetrieveDemo();
}

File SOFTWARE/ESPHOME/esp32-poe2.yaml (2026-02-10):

esphome:
  name: esp32-poe2
  comment: Olimex ESP32-POE2 (WROVER-E N4R8) with UEXT support

esp32:
  board: esp32dev
  framework:
    type: arduino
  psram:
    mode: quad
    speed: 80MHz

logger:

# ================= NETWORKING =================

# ---- WiFi (Primary) ----
wifi:
  ssid: !secret wifi_ssid
  password: !secret wifi_password
  ap:
    ssid: "ESP32-POE2 Fallback"
    password: "fallback123"

captive_portal:

# ---- Ethernet (Secondary / Backup) ----
ethernet:
  type: LAN8720
  mdc_pin: GPIO23
  mdio_pin: GPIO18
  clk_mode: GPIO0_IN
  phy_addr: 0
  power_pin: GPIO12

# ================= ONBOARD IO =================

# ---- User Button (BUT1) ----
binary_sensor:
  - platform: gpio
    name: "BUT1 Button"
    pin:
      number: GPIO34
      mode: INPUT

# ---- External Power Sense ----
sensor:
  - platform: adc
    pin: GPIO39
    name: "External Power Sense"
    attenuation: 11db
    update_interval: 10s

# ================= UEXT CONNECTOR =================

# ---- UART1 on UEXT ----
uart:
  - id: uext_uart
    tx_pin: GPIO4
    rx_pin: GPIO36
    baud_rate: 115200

# ---- I2C Bus on UEXT ----
i2c:
  - id: uext_i2c
    scl: GPIO33
    sda: GPIO13
    scan: true

# ---- SPI Bus on UEXT (shared with SD card pins) ----
# NOTE: Cannot be used together with SD card
spi:
  - id: uext_spi
    clk_pin: GPIO14
    mosi_pin: GPIO2
    miso_pin: GPIO15

# ================= OPTIONAL SD CARD (DISABLED) =================
# Uses same pins as UEXT SPI
# To enable SD, REMOVE the SPI section above first.
#
# spi:
#   clk_pin: GPIO14
#   mosi_pin: GPIO15
#   miso_pin: GPIO2

# ================= CORE SERVICES =================
ota:
api:

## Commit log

2024-04-25 initial upload
    [ESP32-PoE2_Rev_B-B_Cu.gbr, ESP32-PoE2_Rev_B-B_Mask.gbr, ESP32-PoE2_Rev_B-B_Paste.gbr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]
2025-08-21 New demo
    Demo for MOD-ENV and ESP32-POE2
2025-10-16 New demo
    ESP32-POE2 + MOD-RTC
2025-10-24 Update
    Update on the manual and improvement over the UEXT pinout for this board
    [UEXT-PINOUT.ods]
2025-11-03 New Arduino demo
    PSRAM test
2026-01-07 adding files for 3d printed case
    [esp32-poe2 v16_bottom.stl, esp32-poe2 v16_top.stl]
2026-03-27 Update esp32-poe2.yaml
    Updated to be compliant with latest esphome versions
2026-03-27 Update esp32-poe2.yaml
    spelling

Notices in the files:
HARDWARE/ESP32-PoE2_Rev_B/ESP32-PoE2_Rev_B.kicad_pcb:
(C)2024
